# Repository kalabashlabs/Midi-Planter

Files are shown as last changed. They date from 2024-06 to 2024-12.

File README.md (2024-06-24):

# Midi-Planter 1.4
Midi Planter is a midi instrument that senses bio-signals in the roots and the soil of a house plant. The ranges of the bio-signals are mapped to midi notes ands sent to a computer, smartphone or analog synthesizer. 

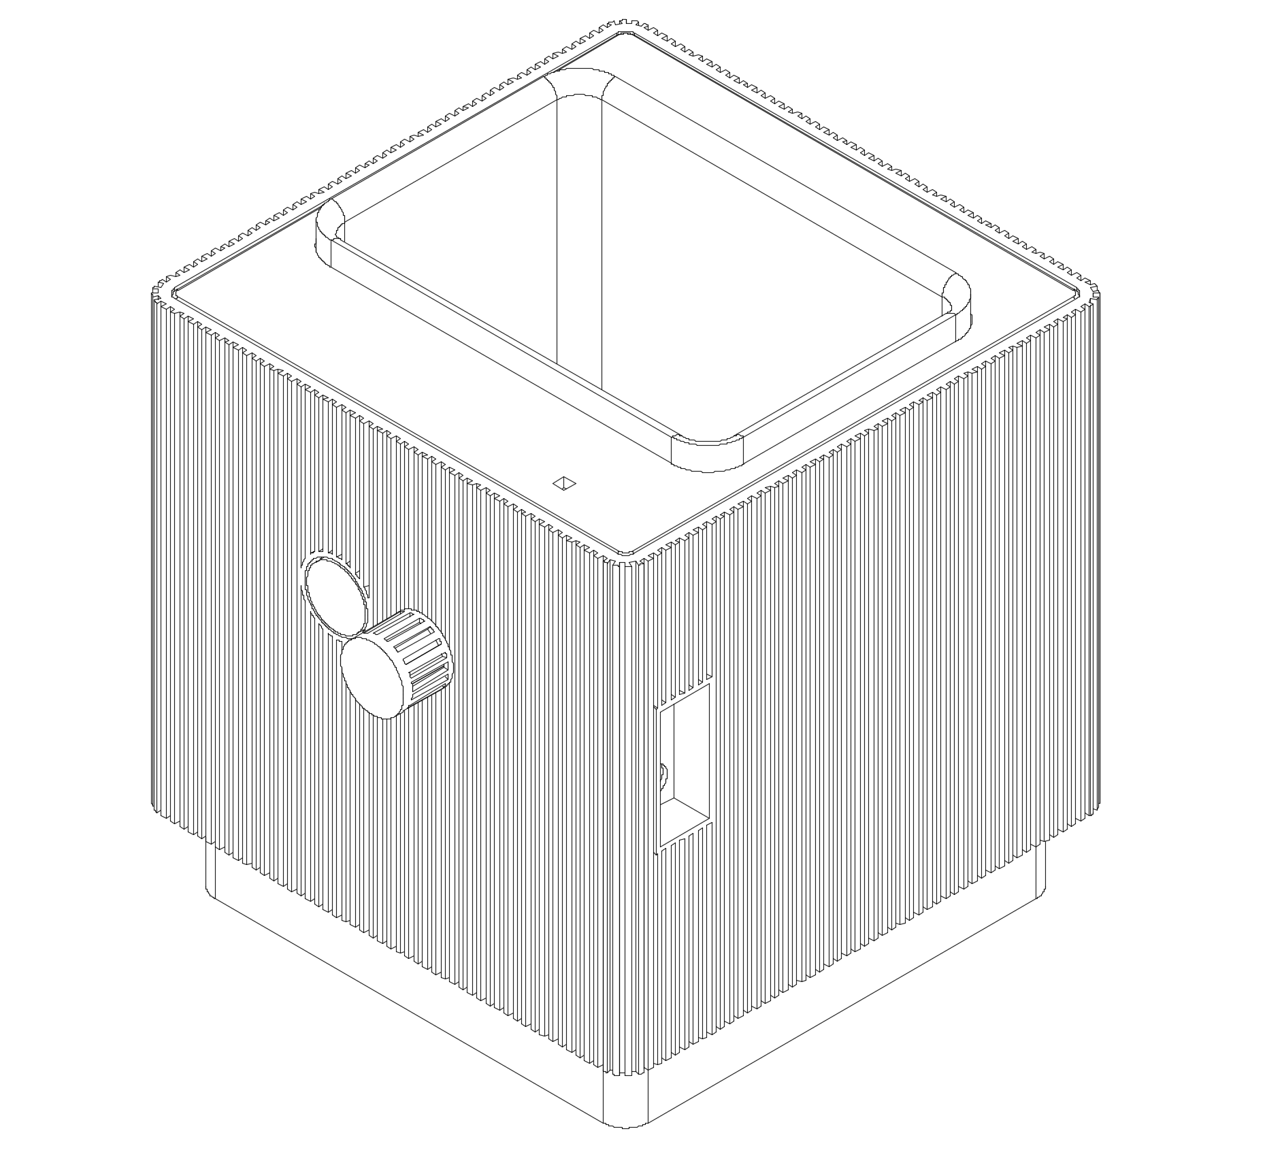
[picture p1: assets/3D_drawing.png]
Sketch of Midi-Planter


## Introduction
This repository contains the source code and documentation for a MIDI device that measures bio signals from plant roots and soil, converting them into MIDI messages using a custom PCB and an Adafruit Trinket M0.

## Features & Compatibility
- **Musical Scales:** Bio signals that are measured can be mapped to Chromatic, Major, Minor, Indian and Dorian.
- **MIDI OFF:** Pause midi messages sent to external device.
- **Open Source:** Designed specifically community collaboration.
- **Adafruit Trinket M0:** Utilizes the Adafruit Trinket M0 for processing and communication.
- **Connectability:** Connect to any instrument that accepts midi-In.  

## Getting Started

### Prerequisites
- PCB Setup Guide
- USB cable
- 3.5mm TRS Cable
- Arduino IDE

### Installation
1. Clone the repository:
   ```sh
   git clone https://github.com/kalabashlabs/Midi-Planter.git
   cd Midi-Planter

### Setup Firmware
Follow the [MP14 Firmware Setup Guide w/Arduino Trinket M0](https://github.com/kalabashlabs/Midi-Planter/tree/9c78c0cd12679d66a3d97c33ffdac4fd24a90cb2/firmware) Guide

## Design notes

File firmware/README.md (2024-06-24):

# MP14 Firmware Setup Guide w/Arduino Trinket M0

## Introduction
This guide will walk you through the steps to connect an Adafruit Trinket M0 to the Arduino IDE on both macOS and Windows. You'll learn how to configure the board and upload the firmware to it.

## Requirements
- Assembled PCB w/Adafruit Trinket M0 [LINK]
- Micro USB cable
- Computer (macOS or Windows)
- Arduino IDE (latest version)

## Step-by-Step Guide

### 1. Install Arduino IDE
1. **Download and Install:**
   - Go to the [Arduino IDE download page](https://www.arduino.cc/en/software) and download the latest version for your operating system.
   - Install the Arduino IDE following the on-screen instructions.

### 2. Install Adafruit Board Support Package
1. **Open Arduino IDE:**
   - Launch the Arduino IDE on your computer.
   
2. **Add Board Manager URL:**
   - Go to `Arduino` > `Preferences` on macOS or `File` > `Preferences` on Windows.
   - In the `Additional Board Manager URLs` field, add the following URL: 
     ```
     https://adafruit.github.io/arduino-board-index/package_adafruit_index.json
     ```
   - Click `OK`.

3. **Open Boards Manager:**
   - Go to `Tools` > `Board` > `Boards Manager`.

4. **Install Adafruit SAMD Boards:**
   - In the Boards Manager, search for `Adafruit SAMD`.
   - Click `Install` on `Adafruit SAMD Boards` by Adafruit.

### 3. Connect Adafruit Trinket M0
1. **Connect the Trinket M0:**
   - Use a USB cable to connect the Trinket M0 to your computer.

2. **Select the Board:**
   - Go to `Tools` > `Board`.
   - Select `Adafruit Trinket M0`.

3. **Select the Port:**
   - Go to `Tools` > `Port`.
   - Select the port that corresponds to your Trinket M0. It should look something like `COMx` on Windows or `/dev/cu.usbmodemxxxx` on macOS.

### 4. Uploading Source Code
1. **Open or Create a Sketch:**
   - Create a new one.
   - Copy and Paste the MP14.14 code to the Arduino sketch

2. **Compile the Sketch:**
   - Click the checkmark icon to verify (compile) your sketch.

3. **Upload the Sketch:**
   - Click the right arrow icon to upload the sketch to the Trinket M0.
   - If the upload is successful, the on-board LED should start blinking.

### 5. Troubleshooting
1. **Driver Issues (Windows):**
   - If your Trinket M0 is not recognized, you might need to install the USB driver. Follow the instructions on the Adafruit website to install the necessary drivers.

2. **Resetting the Trinket M0:**
   - If the upload fails, double-click the reset button on the Trinket M0 to enter bootloader mode (the red LED should pulse). Try uploading the sketch again.

### Conclusion
You have successfully set up your Adafruit Trinket M0 with the Arduino IDE and uploaded your first sketch. 

For more information and troubleshooting, refer to the [Adafruit Learning System](https://learn.adafruit.com/adafruit-trinket-m0-circuitpython-arduino) or the [Arduino Forums](https://forum.arduino.cc/).

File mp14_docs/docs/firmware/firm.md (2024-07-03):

# MP14 Firmware Setup Guide

[See on Github](https://github.com/kalabashlabs/Midi-Planter/tree/abc15cf49541974a32a134d85bc21599ec5fb134/firmware)

## 1. Install Arduino IDE

### Download and Install:

- Go to the [Arduino IDE download page](https://www.arduino.cc/en/software) and download the latest version for your operating system.
- Install the Arduino IDE following the on-screen instructions.

## 2. Install Adafruit Board Support Package

### Open Arduino IDE:

- Launch the Arduino IDE on your computer.

### Add Board Manager URL:

- Go to **Arduino > Preferences** on macOS or **File > Preferences** on Windows.
- In the **Additional Board Manager URLs** field, add the following URL: `https://adafruit.github.io/arduino-board-index/package_adafruit_index.json`
- Click **OK**.

### Open Boards Manager:

- Go to **Tools > Board > Boards Manager**.

### Install Adafruit SAMD Boards:

- In the Boards Manager, search for **Adafruit SAMD**.
- Click **Install** on **Adafruit SAMD Boards** by Adafruit.

## 3. Connect Adafruit Trinket M0

### Connect the Trinket M0:

- Use a USB cable to connect the Trinket M0 to your computer.

### Select the Board:

- Go to **Tools > Board**.
- Select **Adafruit Trinket M0**.

### Select the Port:

- Go to **Tools > Port**.
- Select the port that corresponds to your Trinket M0. It should look something like **COMx** on Windows or **/dev/cu.usbmodemxxxx** on macOS.

## 4. Uploading Source Code

### Open or Create a Sketch:

- Create a new one.
- Copy and paste the MP14.14 code to the Arduino sketch.

### Compile the Sketch:

- Click the checkmark icon to verify (compile) your sketch.

### Upload the Sketch:

- Click the right arrow icon to upload the sketch to the Trinket M0.
- If the upload is successful, the on-board LED should start blinking.

## 5. Troubleshooting

### Driver Issues (Windows):

- If your Trinket M0 is not recognized, you might need to install the USB driver. Follow the instructions on the Adafruit website to install the necessary drivers.

### Resetting the Trinket M0:

- If the upload fails, double-click the reset button on the Trinket M0 to enter bootloader mode (the red LED should pulse). Try uploading the sketch again.

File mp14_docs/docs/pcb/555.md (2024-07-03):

- Solder the 555 timer onto U6

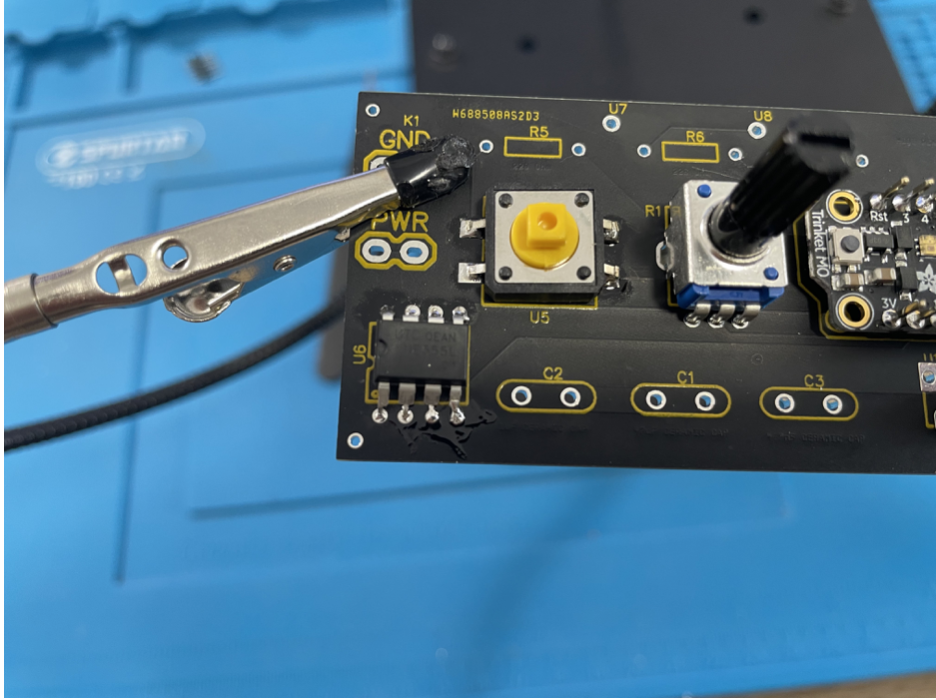
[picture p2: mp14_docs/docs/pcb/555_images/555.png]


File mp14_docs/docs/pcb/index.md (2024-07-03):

# Printed Circuit Board

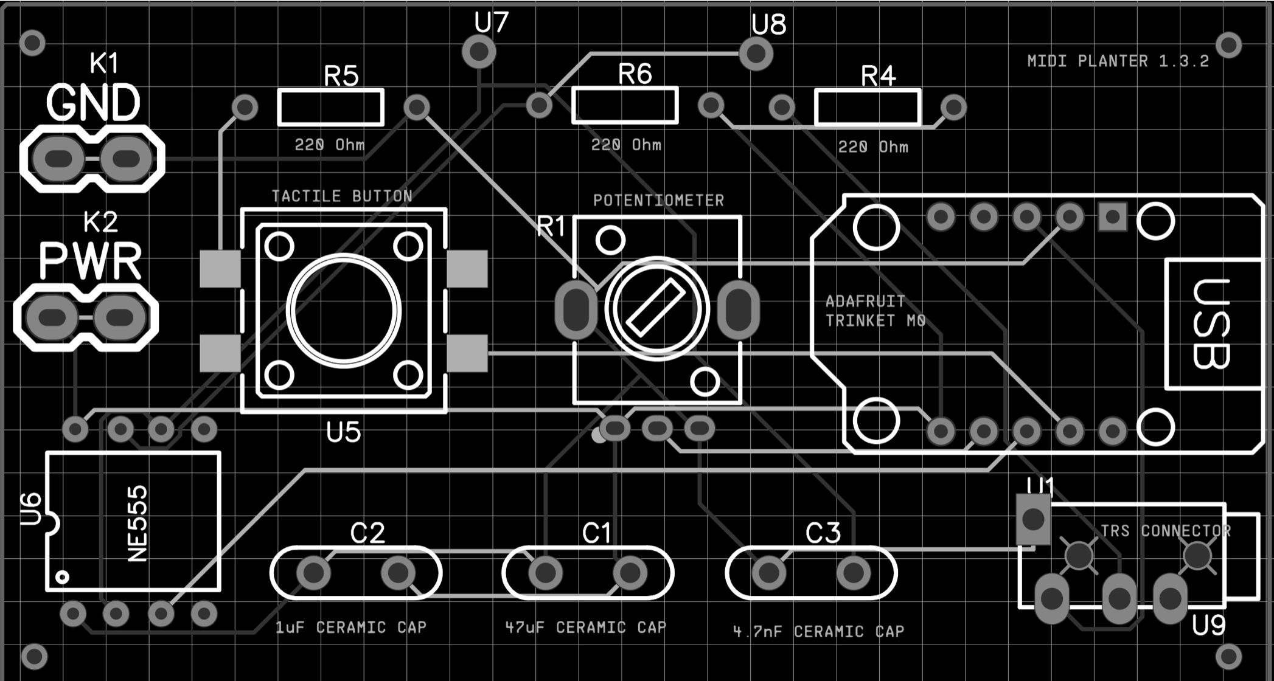
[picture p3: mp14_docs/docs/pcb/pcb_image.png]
pcb


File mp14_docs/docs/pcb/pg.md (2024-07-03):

The GND and PWR connectors are optional for a battery pack. The recommended voltage for the circuit is 3.5V. Two CR2032 cell batteries were tested and worked well.

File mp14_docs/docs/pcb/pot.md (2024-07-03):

- Place the potentiometer into the R1 placement on the PCB. It should fit snug. Solder the Potentiometer onto R1

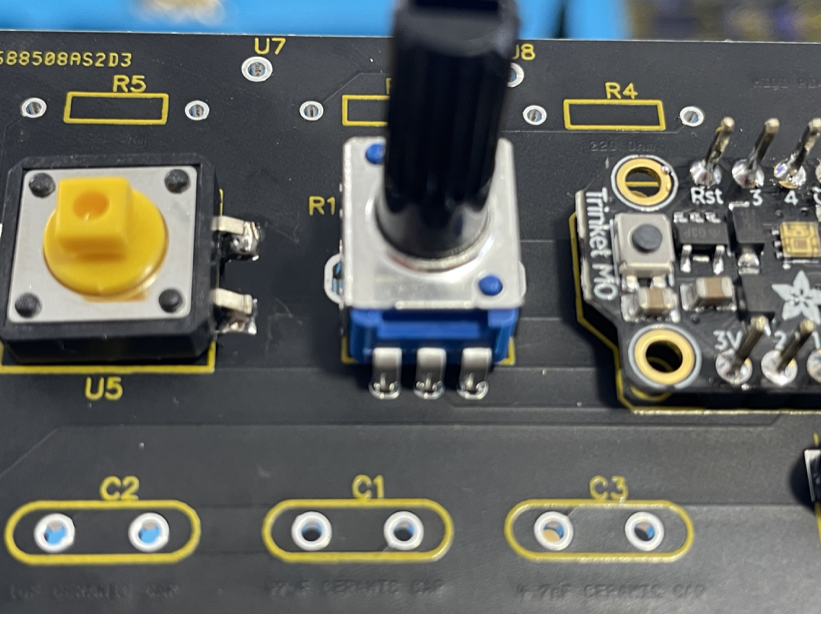
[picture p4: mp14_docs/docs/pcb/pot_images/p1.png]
pot1

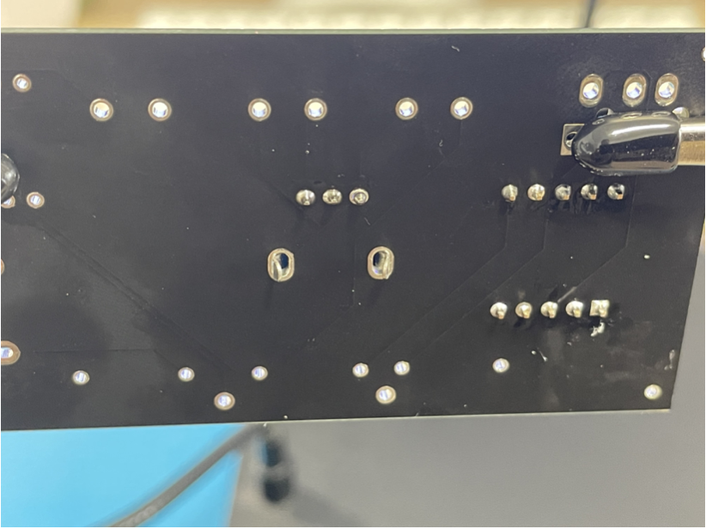
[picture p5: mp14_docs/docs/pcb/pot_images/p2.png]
pot2


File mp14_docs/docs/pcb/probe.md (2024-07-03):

- Cut two pieces of the 0.9mm copper coil at around 72 millimeters.

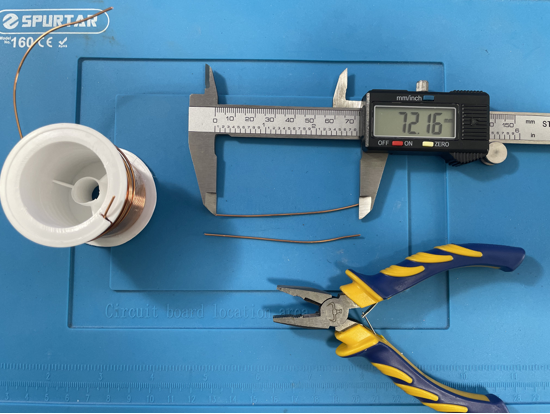
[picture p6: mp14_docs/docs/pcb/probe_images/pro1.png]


- Sand off the insulating layer of the coils with sanding paper. Wear gloves to protect hands from sand paper.

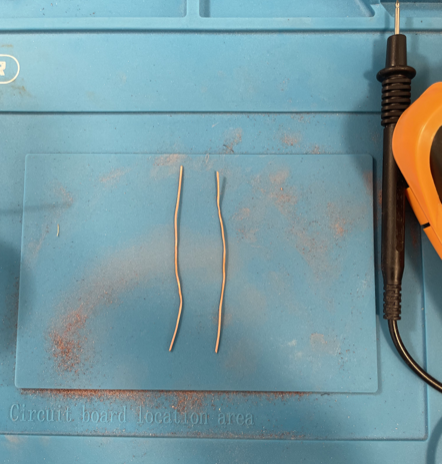
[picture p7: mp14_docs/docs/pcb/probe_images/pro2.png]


- Set your digital multimeter to continuity mode. To test, touch the multimeter probes to the ends of the copper wire one at a time. If the multimeter beeps or buzzes, it indicates successful end-to-end continuity. If there is no sound, it means the insulating layer on the wire needs to be sanded more thoroughly. Test multiple areas of the probe to make sure the insulating layer is evenly sanded off.

- Solder the two copper coil strips to U7 and U8 on the pcb.

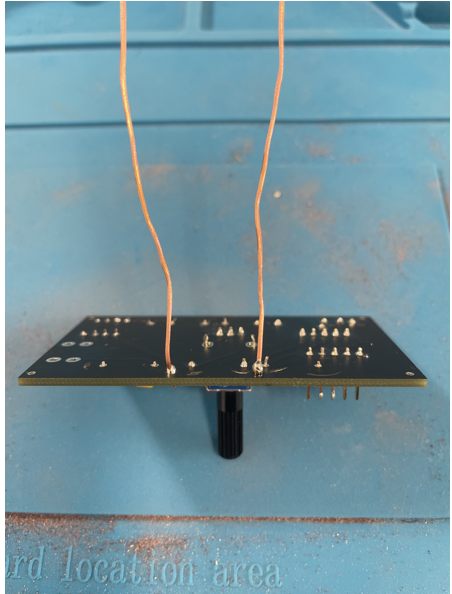
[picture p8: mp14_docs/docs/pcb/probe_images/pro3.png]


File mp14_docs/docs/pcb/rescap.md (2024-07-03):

Solder the resistors and capacitors

- Resistor R5 = 220 ohm
- Resistor R6 = 220 ohm
- Resistor R4 = 220 ohm
- Capacitor C2 = 1uF
- Capacitor C1 =47uf
- Capacitor C3 = 4.7nF

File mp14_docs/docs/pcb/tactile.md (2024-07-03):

- Bend all the pins on the tactile switch so that they are faced outward instead of down. Using a wire cutter or a scissor, cut the pins so they fit onto the U5 area on the PCB. Below is a picture of what it should look like before(left) and after(right).

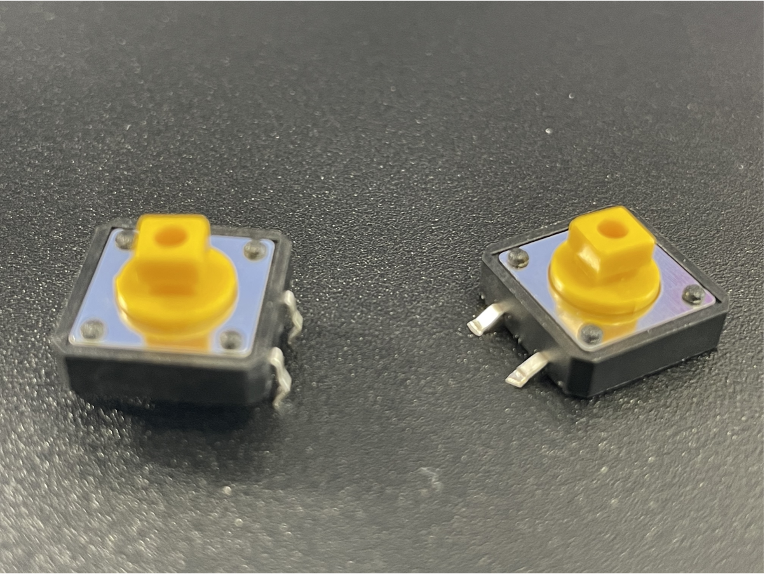
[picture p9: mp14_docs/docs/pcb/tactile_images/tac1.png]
tac1


- With the soldering iron, solder the four onto the four pin areas of U5 then, solder the tactile switch onto U5

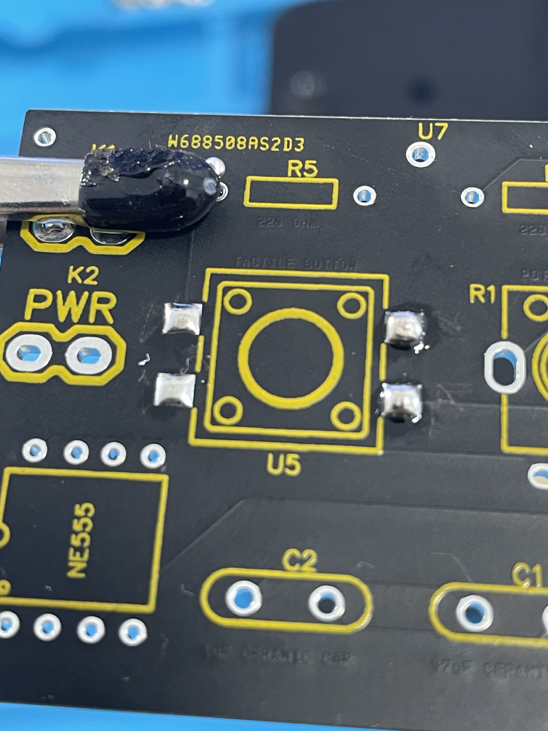
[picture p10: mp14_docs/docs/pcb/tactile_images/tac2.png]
tac2

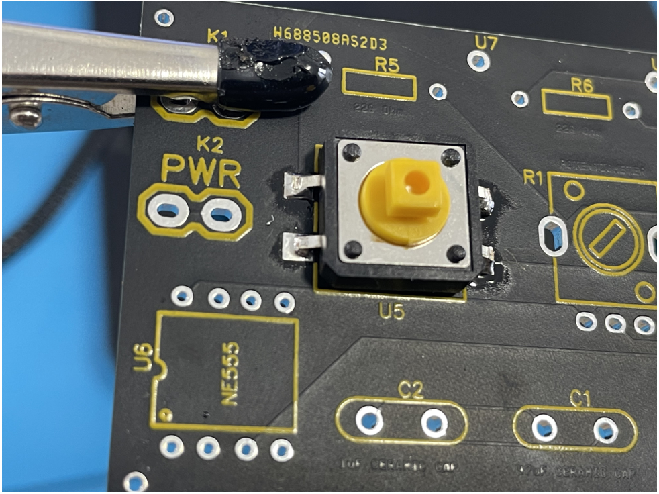
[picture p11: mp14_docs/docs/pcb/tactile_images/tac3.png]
tac3


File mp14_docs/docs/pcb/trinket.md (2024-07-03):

- Snap off 2 sets of 5 header pins that come with the trinket M0. Solder the headers on to the board where the trinket M0 is outlined. The longer sides of the pins should face up.

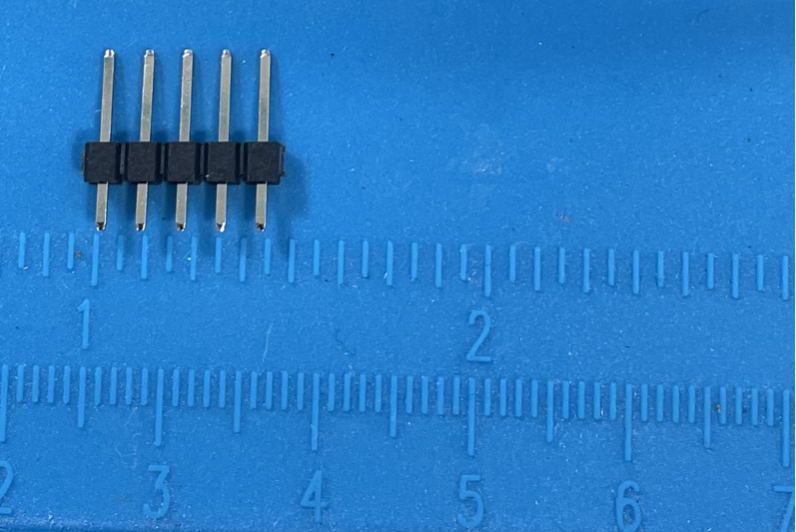
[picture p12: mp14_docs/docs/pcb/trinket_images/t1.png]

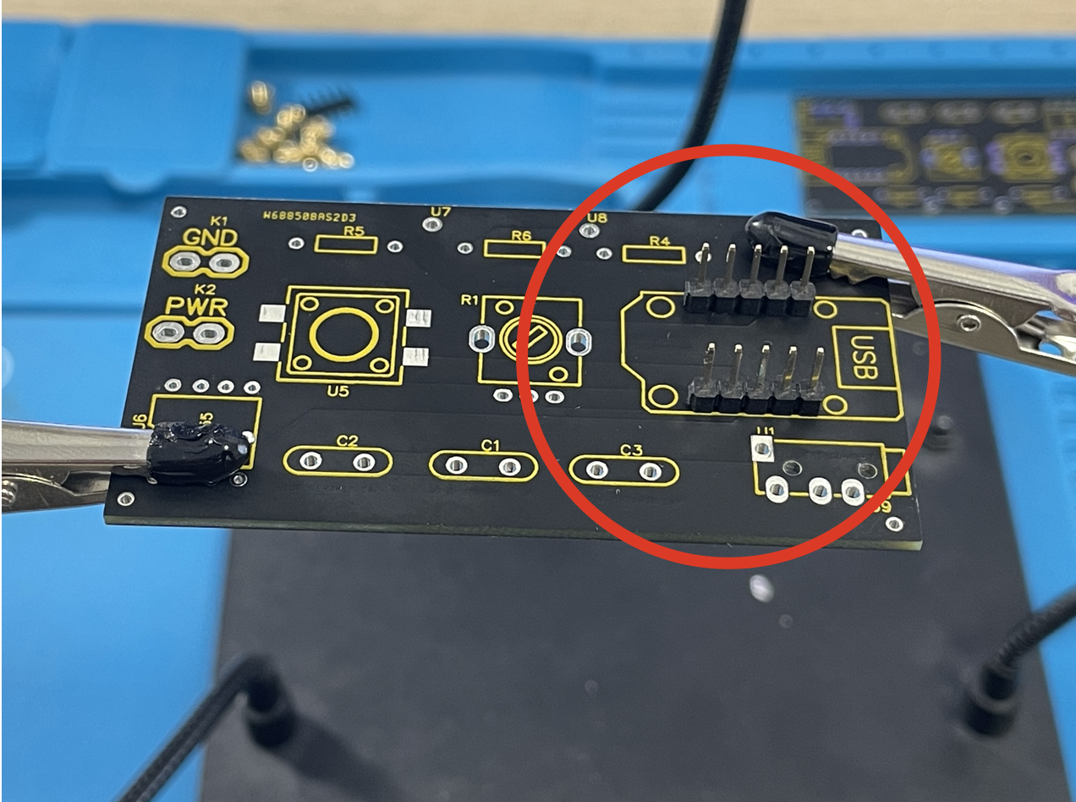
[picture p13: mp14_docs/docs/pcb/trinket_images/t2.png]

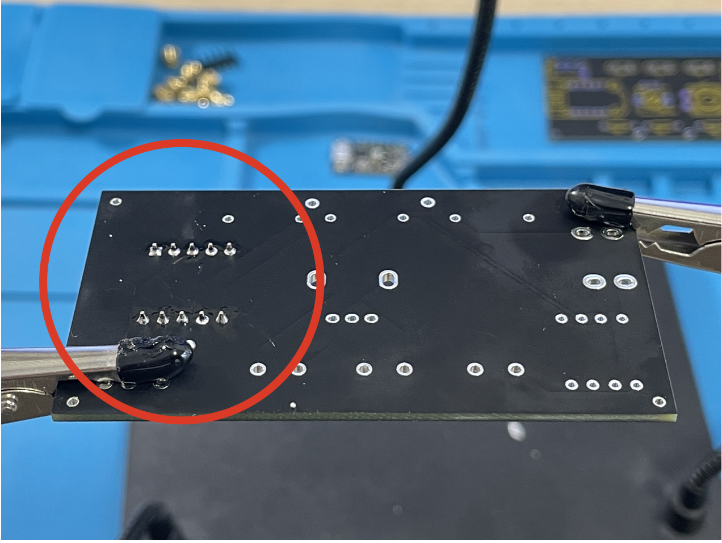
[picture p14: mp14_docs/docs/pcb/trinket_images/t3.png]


- Solder the trinket M0 onto the headers.

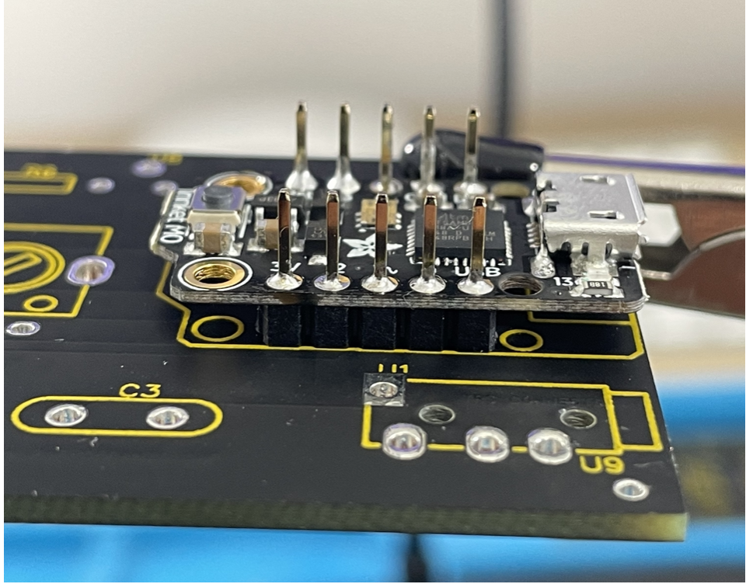
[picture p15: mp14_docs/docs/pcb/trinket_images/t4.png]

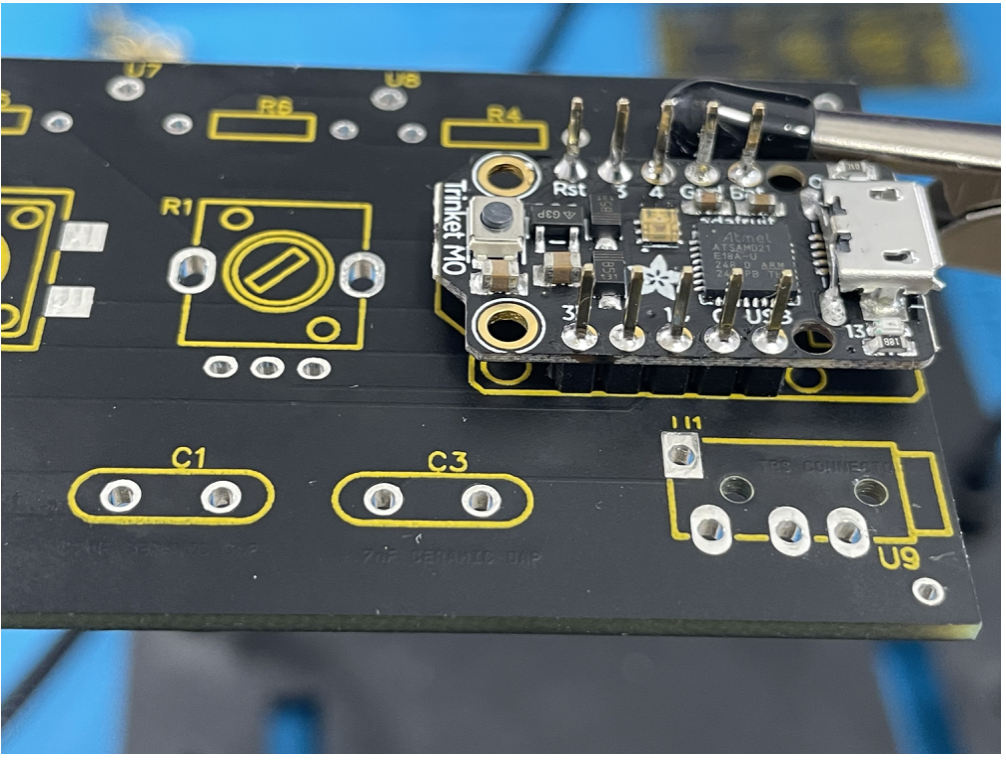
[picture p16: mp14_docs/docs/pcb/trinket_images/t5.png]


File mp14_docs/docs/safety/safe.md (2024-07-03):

# Safety

**Work in a Well-Ventilated Area:**

- Always solder in a well-ventilated space to avoid inhaling fumes. Use a fume extractor if possible.

**Wear Protective Gear:**

- **Safety Glasses:** Protect your eyes from solder splashes.
- **Heat-Resistant Gloves:** Prevent burns from the soldering iron and hot solder.

**Use a Proper Soldering Iron Stand:**

- Always place the soldering iron in a stand when not in use to prevent accidental burns and fire hazards.

**Avoid Flammable Materials:**

- Keep your work area clear of flammable materials. Ensure the soldering iron does not come into contact with paper, plastic, or other flammable objects.

**Handle Soldering Iron Carefully:**

- Never touch the tip of the soldering iron. Be mindful of where you place your hands to avoid accidental burns.

**Clean Soldering Tip Regularly:**

- Use a damp sponge or brass wire cleaner to keep the soldering tip clean, ensuring efficient and safe soldering.

**Avoid Inhaling Solder Fumes:**

- Use lead-free solder to minimize health risks. Ensure good ventilation or use a fume extractor.

**Properly Dispose of Waste:**

- Dispose of used solder and electronic components according to local regulations. Do not throw them in regular trash.

**Sanding Copper Wire Safety**

**Wear Protective Gear:**

- **Safety Glasses:** Protect your eyes from copper dust and particles.
- **Dust Mask:** Prevent inhalation of copper dust.
- **Gloves:** Protect your hands from the sanding skin with sandpaper.

**Secure the Wire: (Optional)**

- Use a vise or clamp to securely hold the copper wire in place while sanding to prevent slipping and accidental injury. [Vise Clamp](https://www.printables.com/model/65687/files)

**Use Appropriate Sanding Tools:**

- Use fine-grit sandpaper to remove the insulator layer. Avoid using power tools, as they can remove too much material and generate excessive dust.

**Work in a Well-Ventilated Area:**

- Sand in a well-ventilated space to ensure you are not breathing in copper dust. An outdoor workspace is ideal.

**Clean Up Properly:**

- After sanding, clean the work area thoroughly to remove copper dust. Wash your hands and any exposed skin to avoid prolonged contact with copper particles.

**Avoid Excessive Force:**

- Apply gentle, even pressure while sanding to avoid damaging the wire and to maintain control of the sanding process.

**Store Tools Safely:**

- After use, store sandpaper and other tools in a safe place to prevent accidental contact.

## General Safety Tips

**Read Instructions Carefully:**

- Follow all steps as outlined in the manual. Do not skip steps or take shortcuts.

**Keep a First Aid Kit Handy:**

- In case of minor injuries, have a first aid kit available for immediate treatment.

**Seek Help If Needed:**

- Don't hesitate to ask for assistance if you're unsure about any part of the process.

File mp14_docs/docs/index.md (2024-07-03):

# MP14 Overview

Kalabash Labs' MP14 is a planter and a polyphonic MIDI controller which utilizes bioelectrical signals from living organisms inside of soil as a source of input, converting them into control voltages that can be interpreted as notes within any desired chromatic scale.

**Features and Compatibility**

- Musical Scales: Bio signals that are measured can be mapped to Chromatic, Major, Minor, Indian and Dorian.
- MIDI OFF: Pause midi messages sent to external device.
- Open Source: Designed specifically community collaboration.
- Adafruit Trinket M0: Utilizes the Adafruit Trinket M0 for processing and communication.
- Connectability: Connect to any instrument that accepts midi-In.

**References**

- [galvanic_midi](https://github.com/jarvisb1/galvanic_midi/tree/master)
- [Biodata Sonification Breadboard Kit](https://github.com/electricityforprogress/BiodataSonificationBreadboardKit)

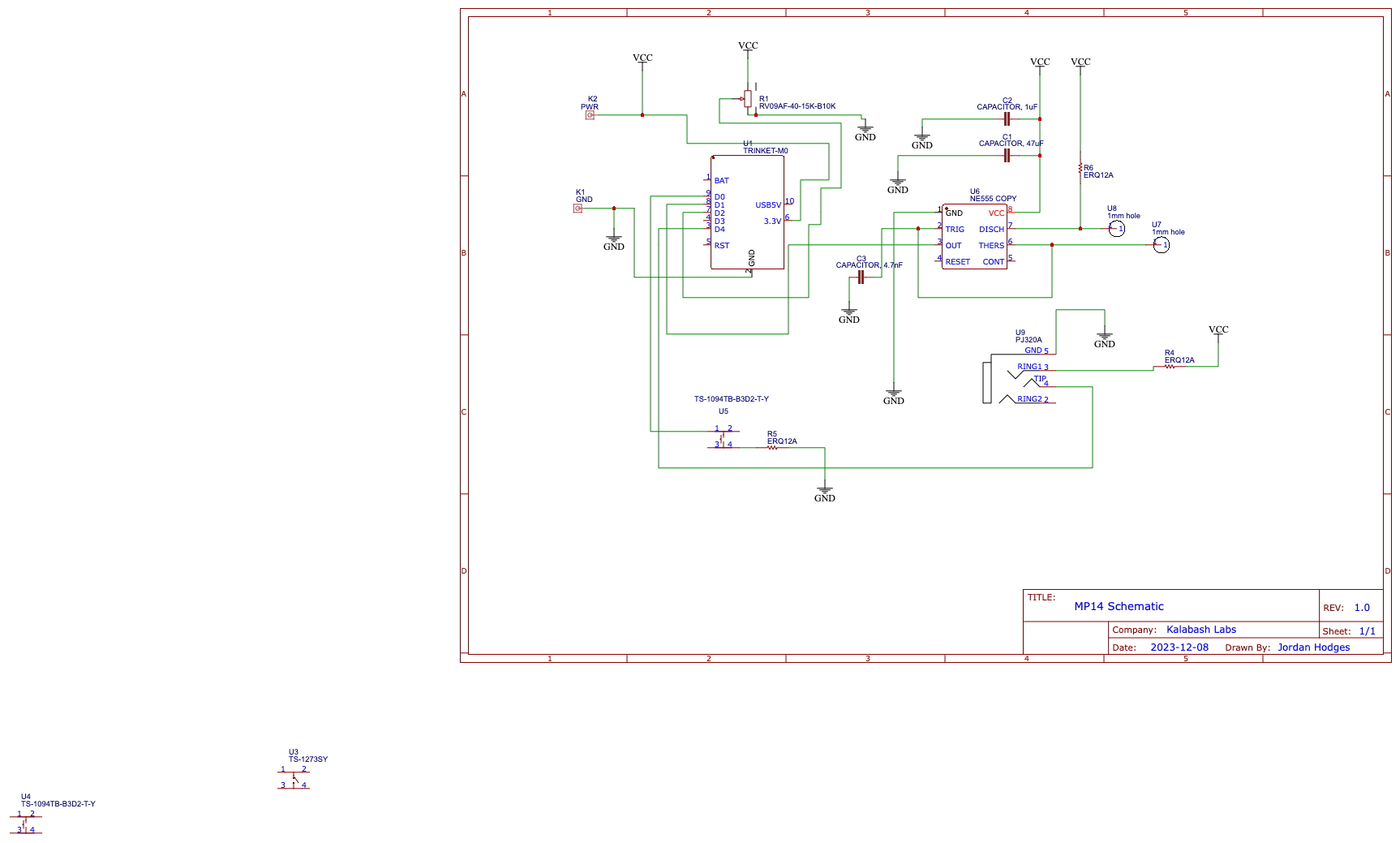
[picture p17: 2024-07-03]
assets/schematics/Schematic_MIDI-PLANTER1_4.png

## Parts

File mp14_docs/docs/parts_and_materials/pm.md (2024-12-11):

# Parts and Materials

**PCB Parts**

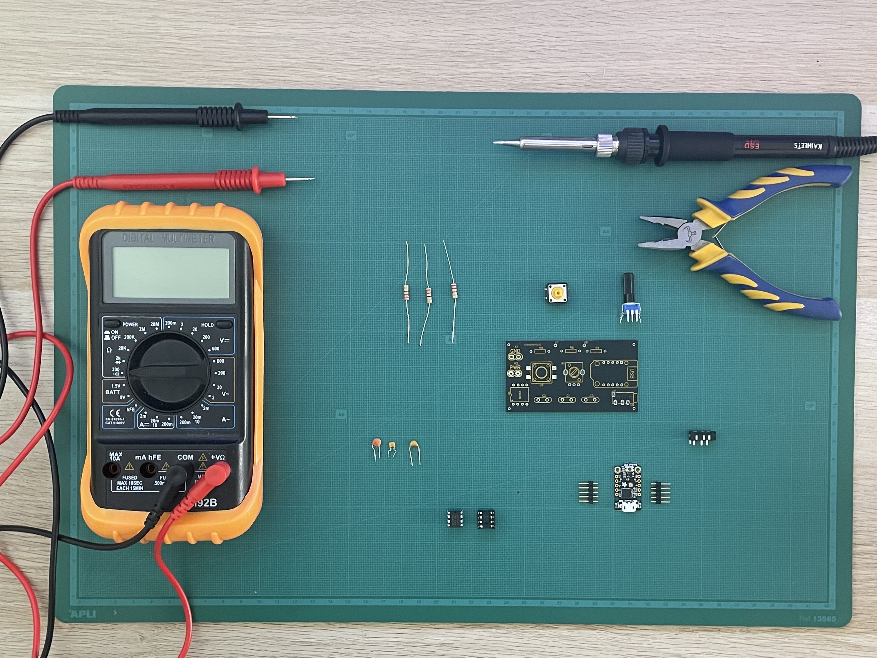
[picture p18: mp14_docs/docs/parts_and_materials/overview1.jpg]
PCB_Image


Below is a list of components needed to assmeble the pcb. It is recommended to source these components locally from a Maker Space/ Fabrication Lab or a local electronics store. You can find the Gerber file for the PCB [here](https://github.com/kalabashlabs/Midi-Planter/tree/38d511a70ebe548d43128dbe252c7a7642a91098/assets/schematics).

| Part | Online | Quantity |
| --- | --- | --- |
| Adafruit Trinket M0 | [Adafruit](https://www.adafruit.com/product/3500) | 1 |
| 555 Timer | [AMZN_ES](https://shorturl.at/HQzQk) / [AMZN_US](https://shorturl.at/2IgPi) | 1 |
| 220 Ohm Resistor | [Adafruit](https://www.adafruit.com/product/2780) | 3 |
| 1 uF 35V Ceramic Capacitor | [AMZN_ES]() / [AMZN_US](https://shorturl.at/93tgW) | 1 |
| 47 uF Ceramic Capacitor | [AMZN_ES](https://shorturl.at/sUhQ8) / [AMZN_US]() | 1 |
| 470 pF Ceramic Capacitor | [AMZN_ES](https://shorturl.at/R7DZH) / [AMZN_US]() | 1 |
| TRS Connector PJ320A | [AMZN_ES](https://shorturl.at/5Rtxn) / [AMZN_US]() | 1 |
| Tactile Switch | [Adafruit](https://www.adafruit.com/product/1009) | 1 |
| Potentiometer | [Diotronic](https://diotronic.com/de-ajuste-con-eje/11321-poten-vertical-10k-pcb-eje-6mm) | 1 |
| 0.9mm Copper Coil | [AMZN_ES](https://shorturl.at/LzUeT) / [AMZN_US]() | 1 |

**3D Printed Parts & Materials**

3D

- Planter
- PCB Bracket
- Hood
- Shell
- Pool
- Button
- Knob

These 3D Design Files can be found [here](https://github.com/kalabashlabs/Midi-Planter/tree/38d511a70ebe548d43128dbe252c7a7642a91098/assets/stl)

Below is a list of screws and nuts needed to assemble the 3D parts.

| Part | Online | Quantity |
| --- | --- | --- |
| M4 Screws | [Adafruit](https://www.adafruit.com/product/3500) | 6 |
| M4 Brass Nut Inserts | [AMZN_ES](https://shorturl.at/HQzQk) / [AMZN_US](https://shorturl.at/2IgPi) | 6 |

**Tools Needed for Assembly**

- Soldering Iron
- Solder
- 3D Printer
- Multimeter

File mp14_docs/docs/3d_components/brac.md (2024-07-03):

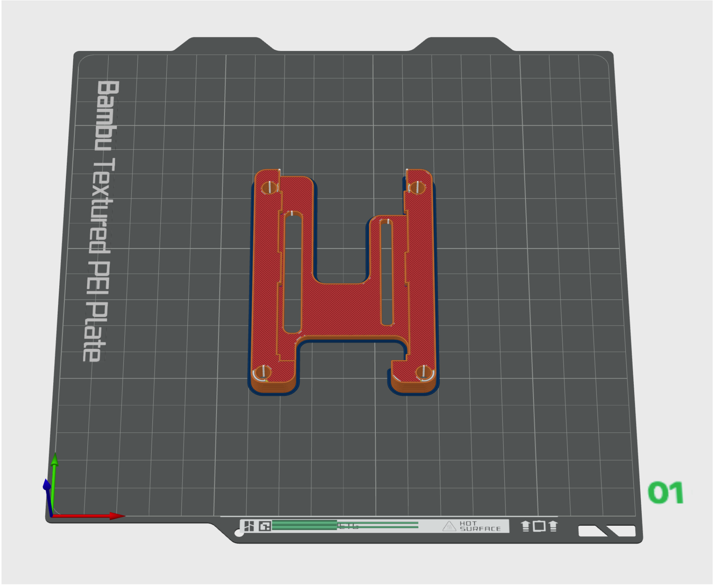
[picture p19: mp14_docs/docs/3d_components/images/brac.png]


PRINT SETTINGS:

- Material: PLA
- Layer Height: 0.3 mm
- Sparse Infill Density: 30%
- Support: No

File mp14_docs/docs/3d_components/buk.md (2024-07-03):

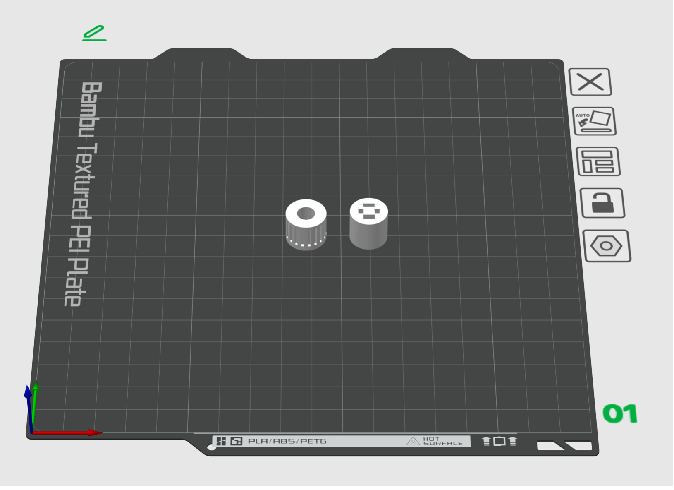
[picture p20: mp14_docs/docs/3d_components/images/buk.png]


PRINT SETTINGS:

- Material: PLA
- Layer Height: 0.3 mm
- Sparse Infill Density: 30%
- Support: No

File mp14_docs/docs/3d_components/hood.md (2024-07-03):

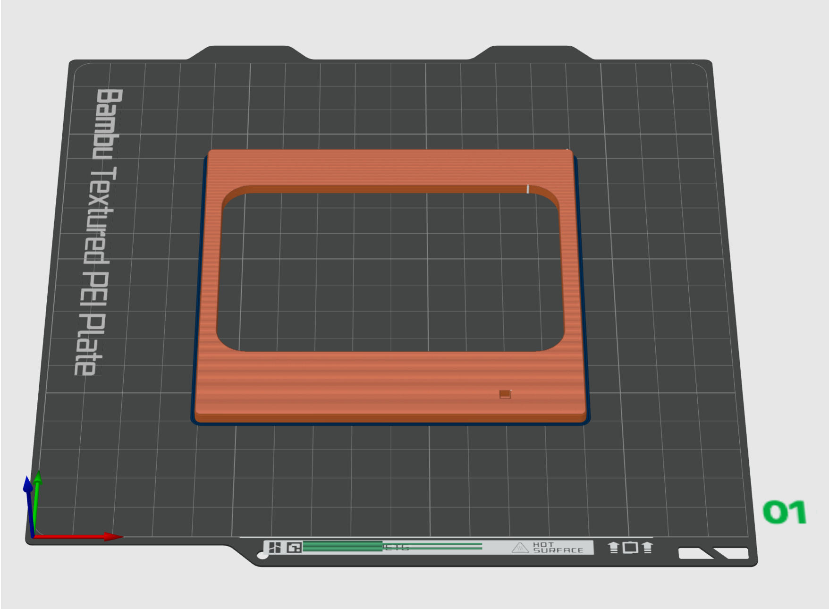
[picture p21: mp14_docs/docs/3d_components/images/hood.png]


PRINT SETTINGS:

- Material: PLA
- Layer Height: 0.3 mm
- Sparse Infill Density: 30%
- Support: No

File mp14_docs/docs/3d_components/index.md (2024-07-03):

# 3D Printed Components

These example printed components were printed using a Bambu Labs A1 mini. The recommended print settings are listed for Bambu Studio.

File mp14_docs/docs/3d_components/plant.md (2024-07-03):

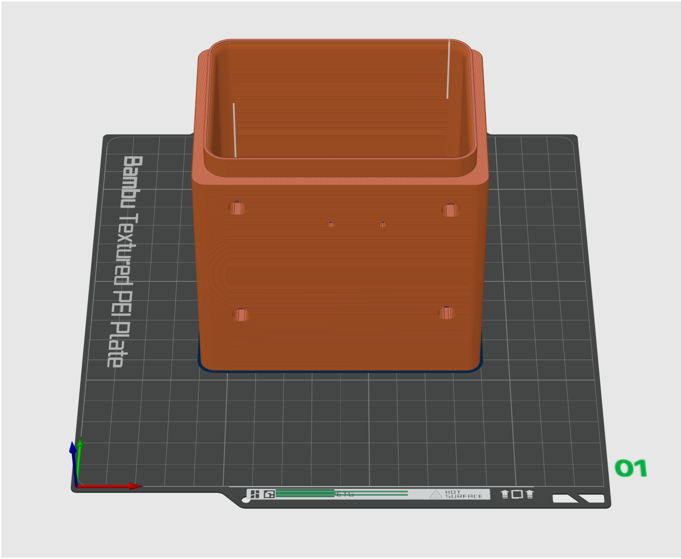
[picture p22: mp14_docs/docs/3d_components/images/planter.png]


PRINT SETTINGS:

- Material: PLA
- Layer Height: 0.3 mm
- Sparse Infill Density: 30%
- Support: No

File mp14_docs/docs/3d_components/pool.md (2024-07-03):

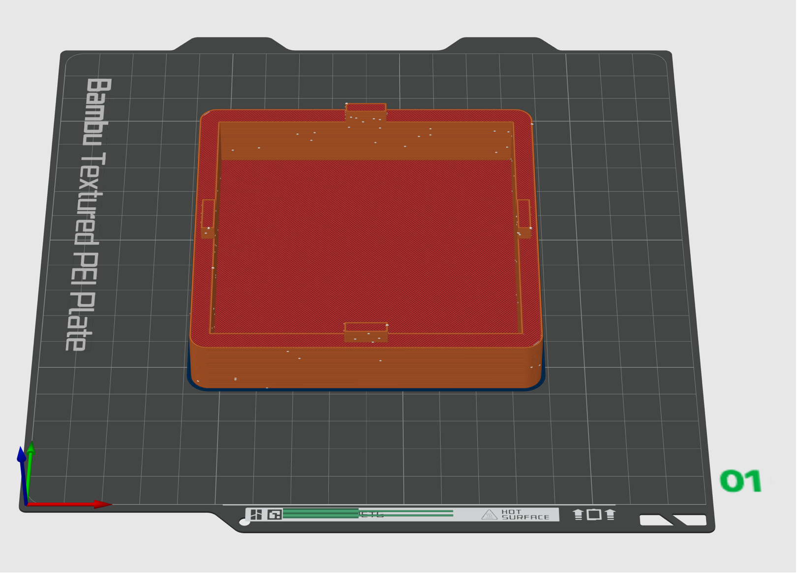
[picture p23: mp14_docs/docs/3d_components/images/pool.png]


PRINT SETTINGS:

- Material: PLA
- Layer Height: 0.3 mm
- Sparse Infill Density: 30%
- Support: No

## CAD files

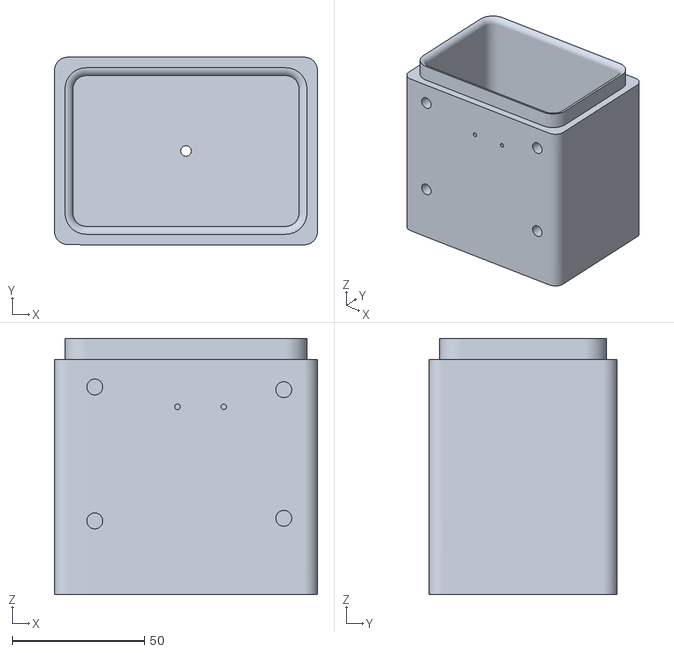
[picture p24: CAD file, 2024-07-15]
assets/stl/PLANTER.stl
99.5 x 71.0 x 97.0

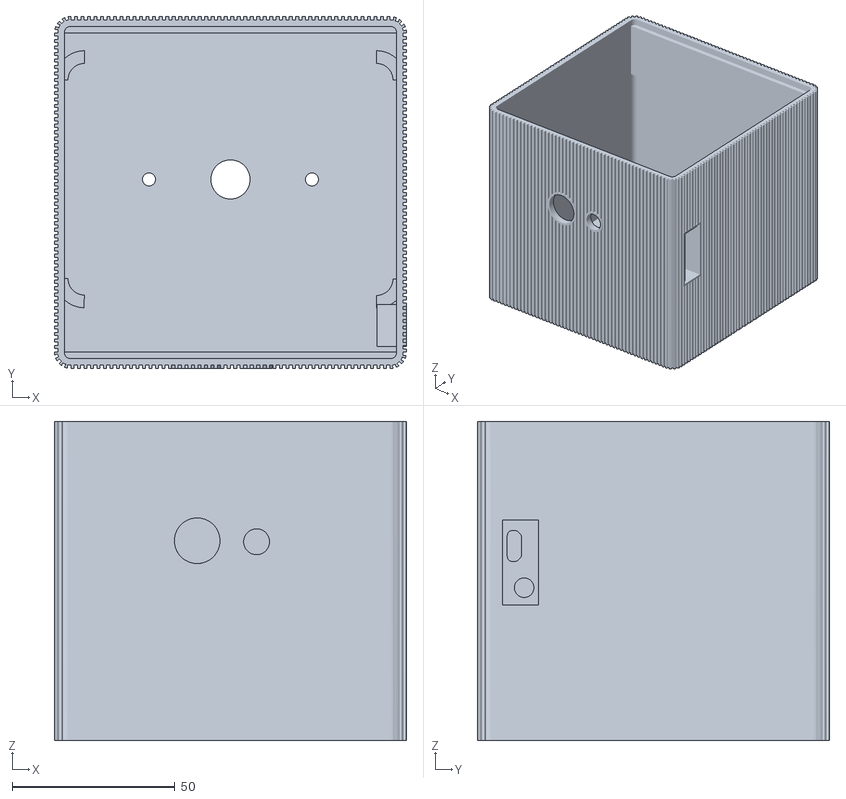
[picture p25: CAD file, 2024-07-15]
assets/stl/SHELL.stl
108.0 x 108.0 x 98.0

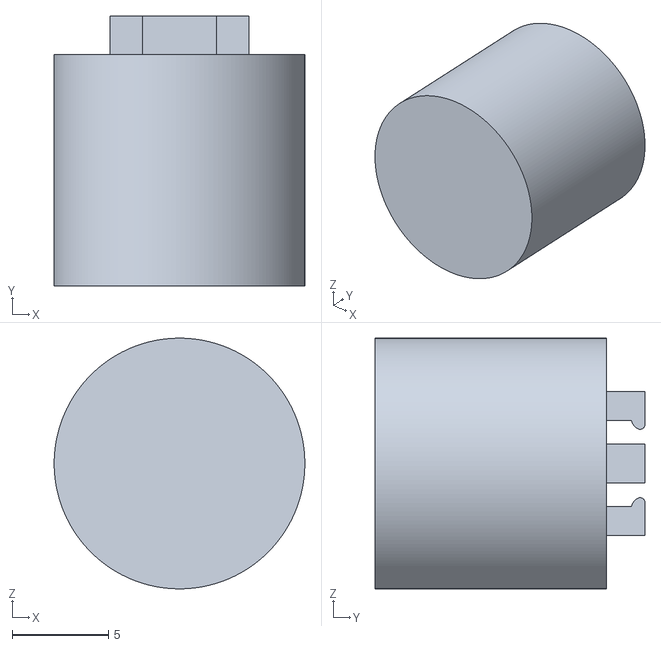
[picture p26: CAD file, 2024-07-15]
assets/stl/BUTTON.stl
13.0 x 14.0 x 13.0

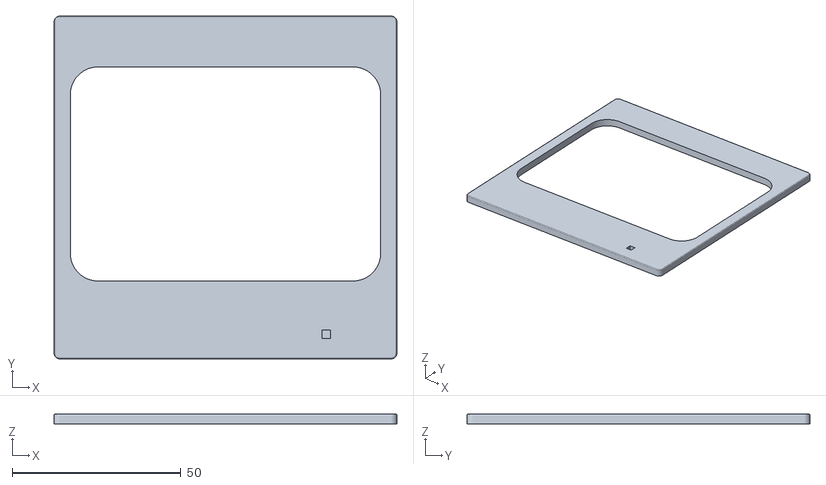
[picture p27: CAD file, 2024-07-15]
assets/stl/HOOD.stl
101.6 x 101.6 x 3.00

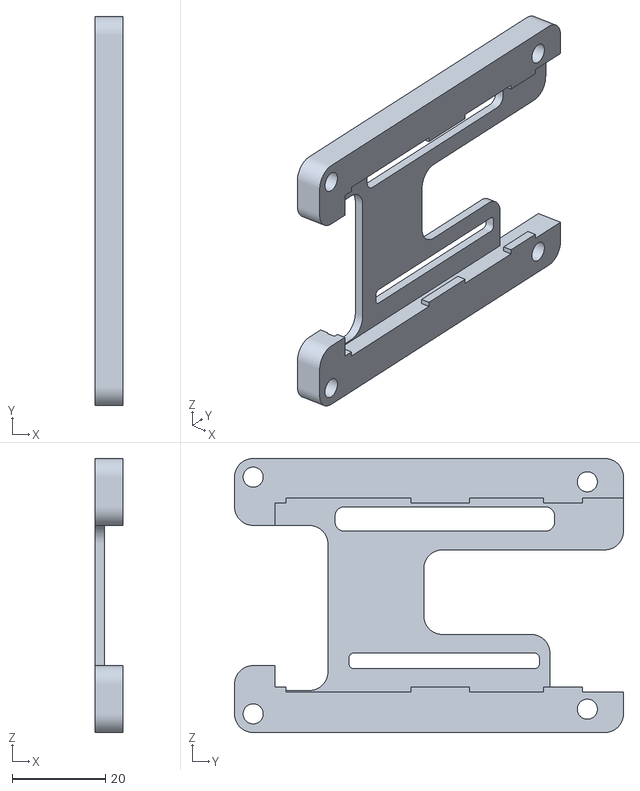
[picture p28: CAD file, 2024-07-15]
assets/stl/BRACKET.stl
6.00 x 83.3 x 58.7

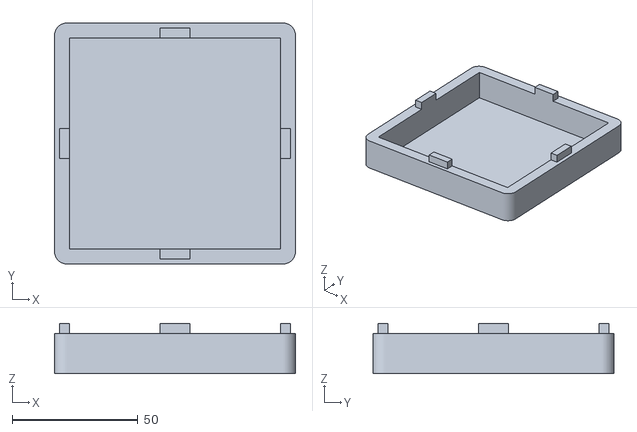
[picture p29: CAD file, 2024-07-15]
assets/stl/POOL.stl
96.0 x 96.0 x 20.0

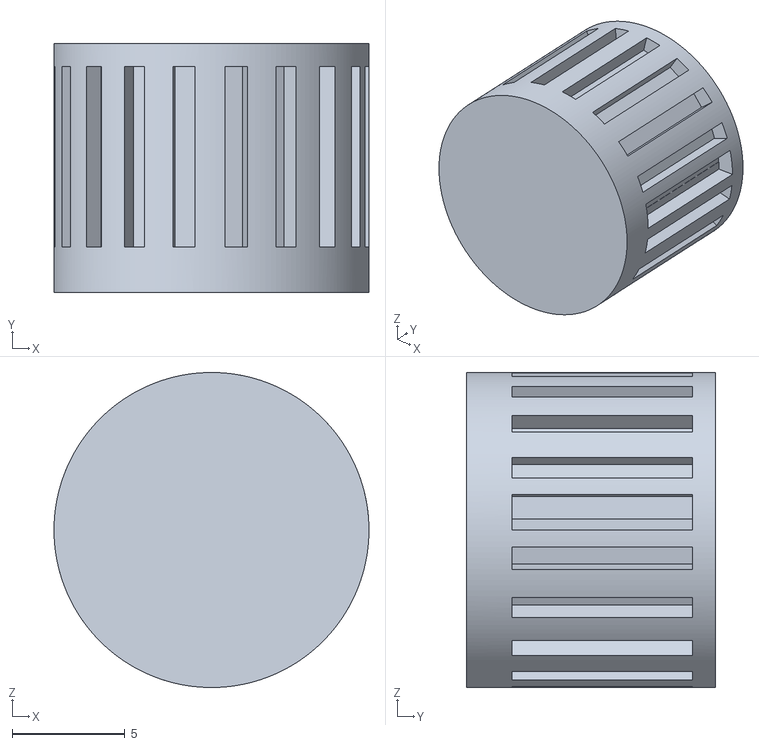
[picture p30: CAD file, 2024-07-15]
assets/stl/KNOB.stl
13.9 x 11.0 x 13.9

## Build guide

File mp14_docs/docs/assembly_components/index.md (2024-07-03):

Place the PCB board inside the bracket. The probes should go through the larger oval.

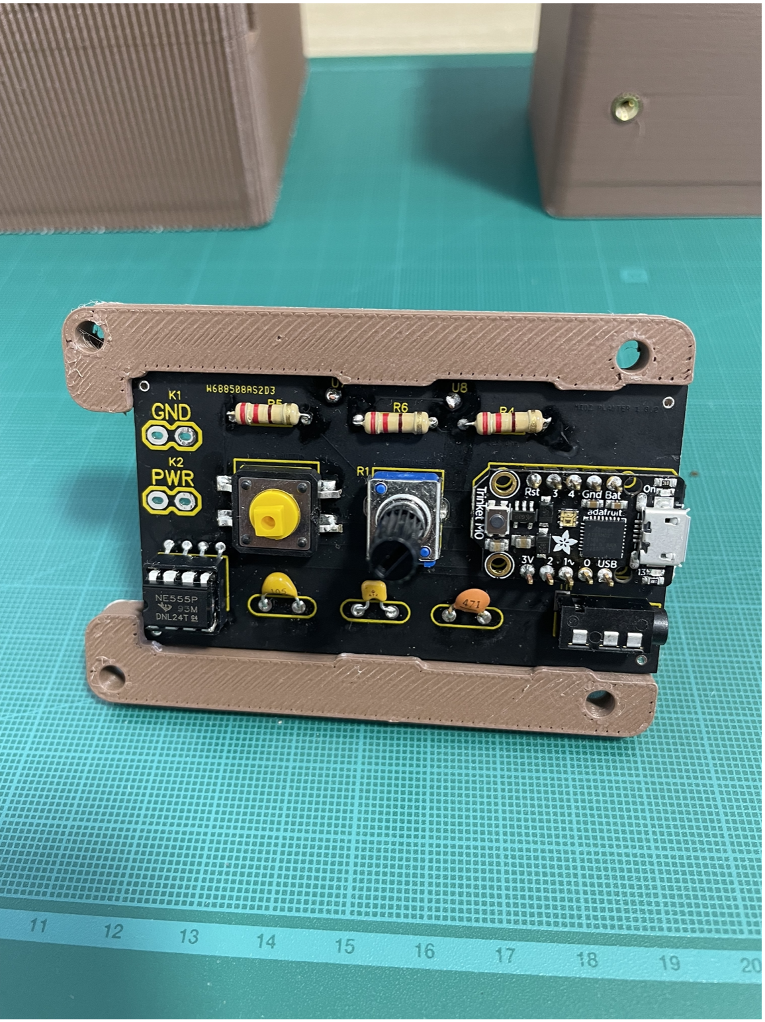
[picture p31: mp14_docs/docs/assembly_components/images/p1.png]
p1

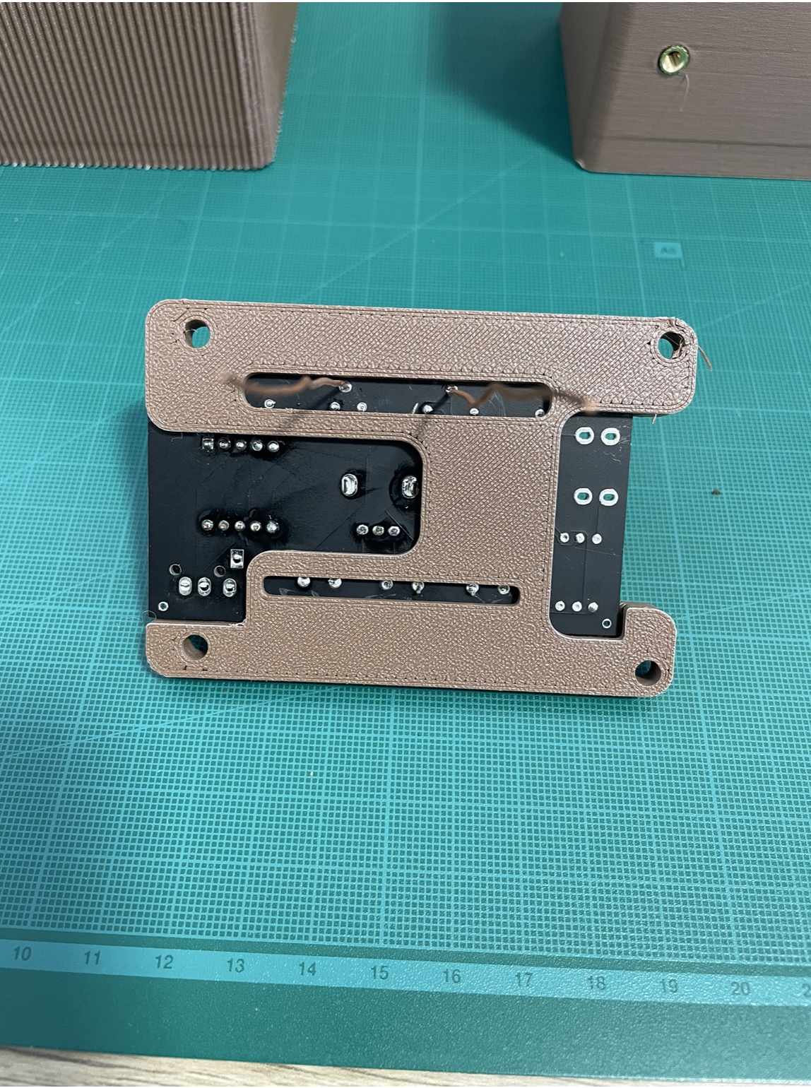
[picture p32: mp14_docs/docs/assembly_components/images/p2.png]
p2


Place four of the M4 brass inserts in the four holes on the front side of the planter. The smaller diameter side of the brass inserts should go inside the hole first.

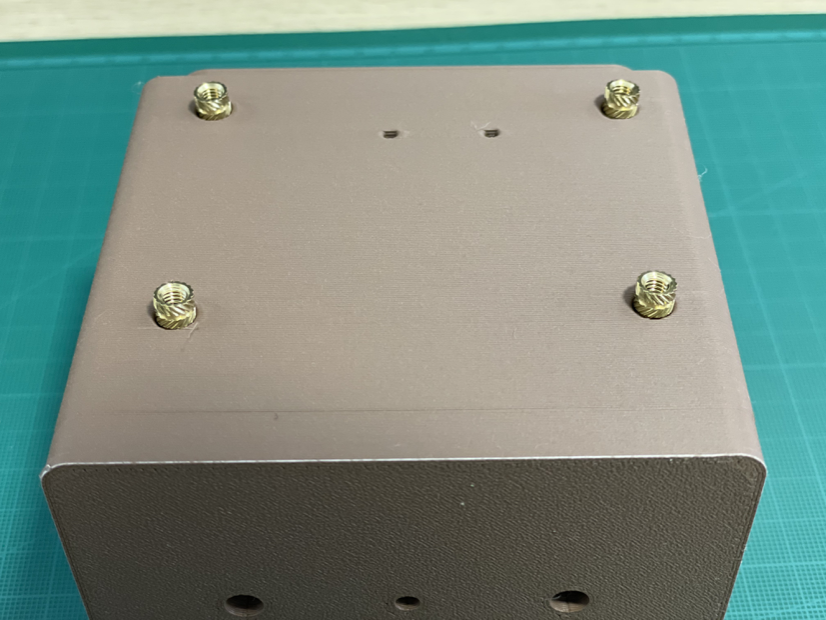
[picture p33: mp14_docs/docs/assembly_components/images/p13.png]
p13


With a soldering iron, hold the tip of the iron onto one brass insert and gently wait for the insert to slide into place. The heat of the iron contacting the insert will expand the PLA material so the insert will fit snug into the hole. Do this for all four holes.

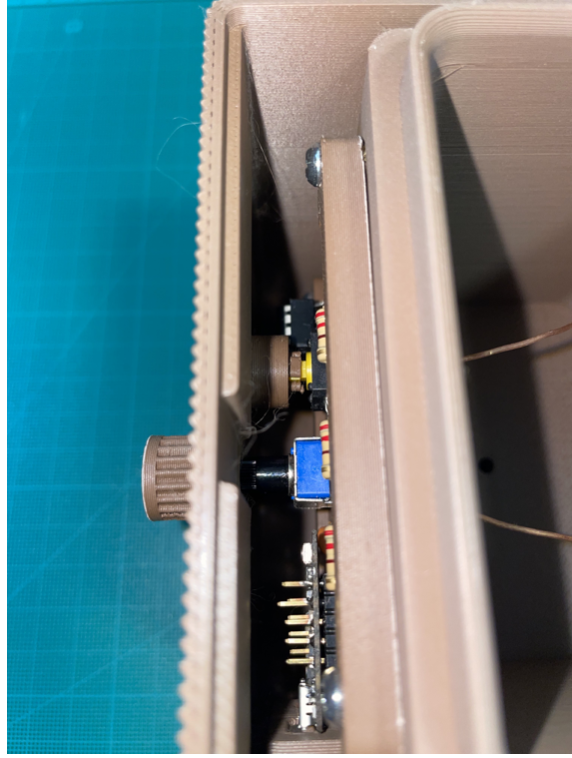
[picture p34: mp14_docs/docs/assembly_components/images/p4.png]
p4

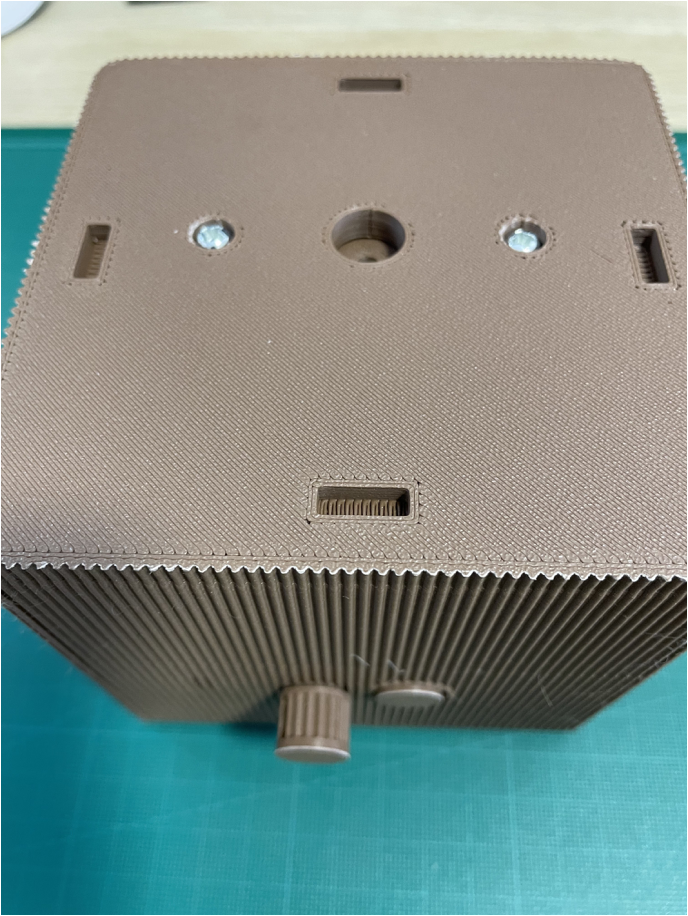
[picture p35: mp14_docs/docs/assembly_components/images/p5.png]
p5


Use the same technique from step 2 to place the inserts into the two holes at the bottom of the planter.

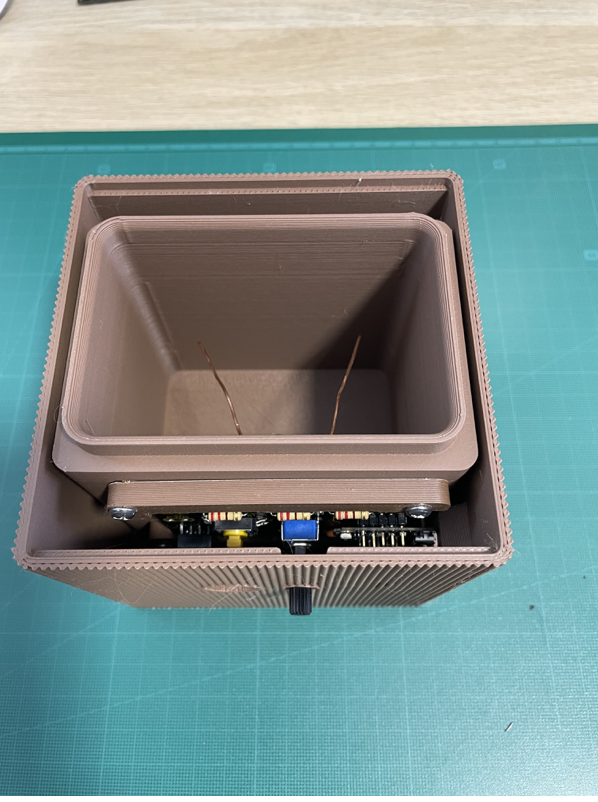
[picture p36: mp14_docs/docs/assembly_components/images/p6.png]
p6


Line the bracket up with the front of the planter and place four M4 screws through the four holes of the PCB Bracket. The copper wires goes through the two small holes on the front of the planter. Then, screw the four M4 screws to the planter with a screw driver.

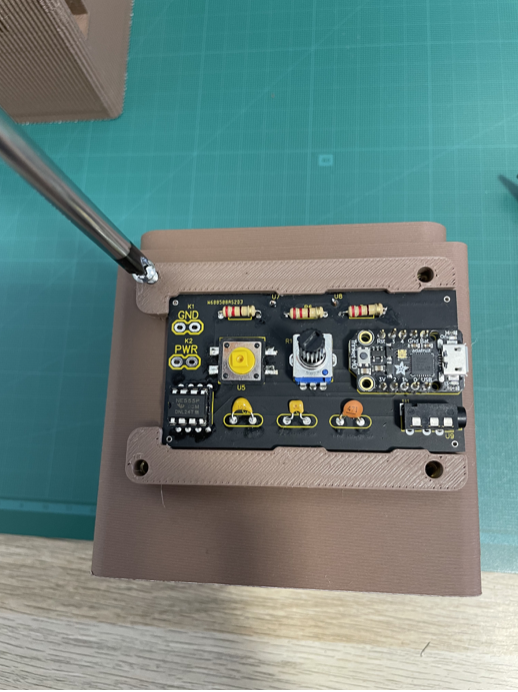
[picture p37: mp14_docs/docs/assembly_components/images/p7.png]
p7

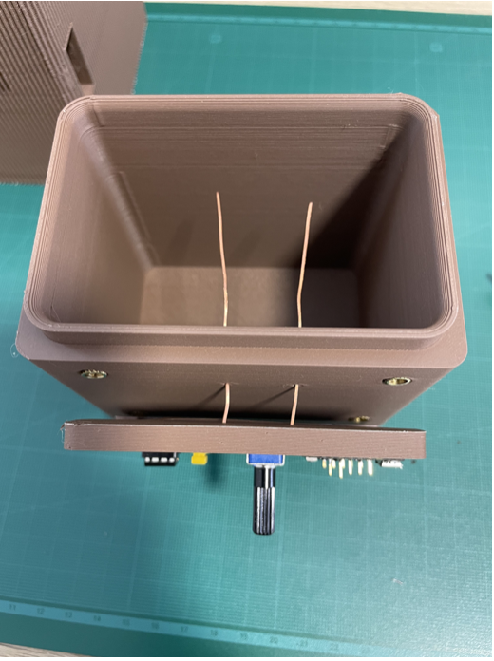
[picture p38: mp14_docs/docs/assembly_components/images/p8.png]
p8


Place the planter inside of the shell. The back of the planter should slide against the inside back of the shell so the potentiometer can fit. Once the bottom of the planter makes contact with the shell, slide the planter forward to fit into the groove while the potentiometer sticks out of the front hole.

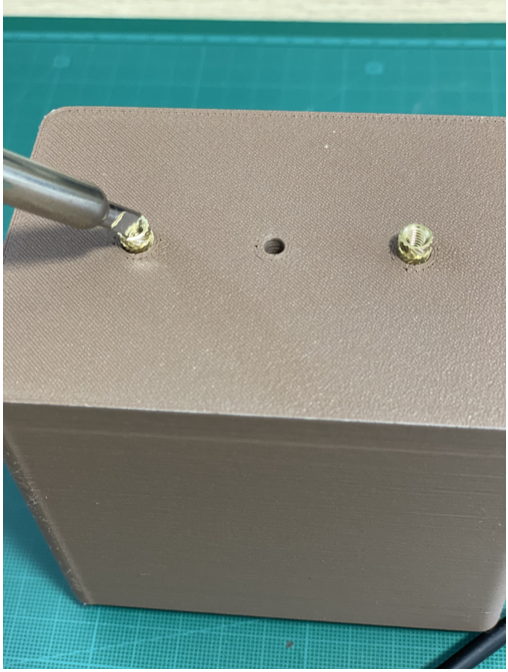
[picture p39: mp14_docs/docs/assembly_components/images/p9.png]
p9


Using pliers or scissors, remove access PLA that is blocking the two holes at the bottom of the shell.

Place the planter and shell upside down and screw two M4 screws into the two holes with a screw driver.

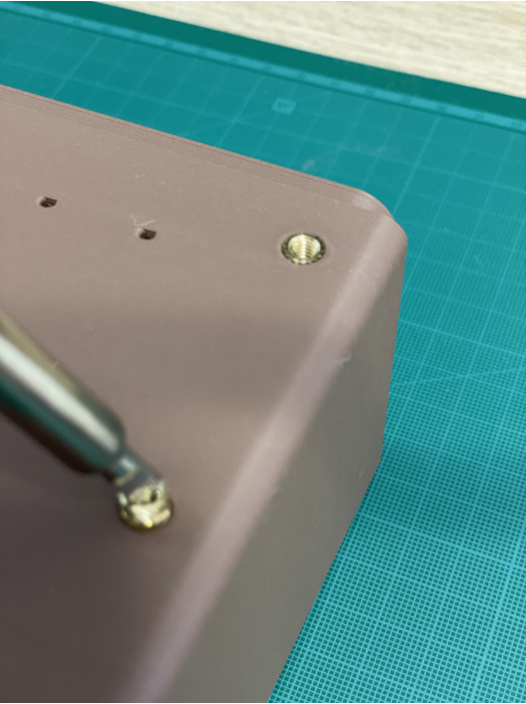
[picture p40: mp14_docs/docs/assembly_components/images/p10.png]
p10


Slide the knob onto the area of potentiometer sticking out of the shell.
Snap the button onto the tactile switch from the front of the shell. Make sure the square on the button is aligned with the square on the tactile switch.

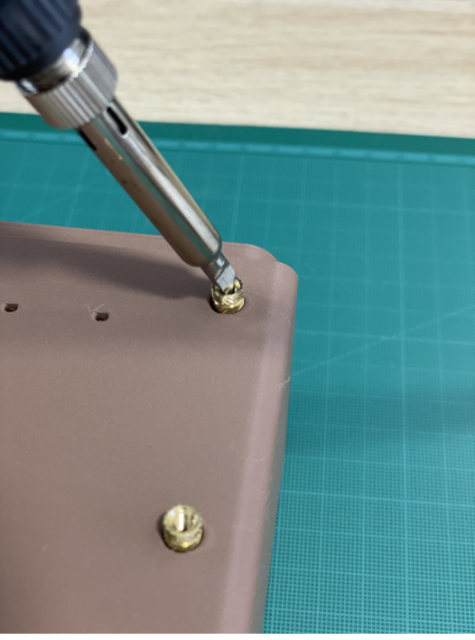
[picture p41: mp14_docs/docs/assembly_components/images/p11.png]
p11


Place the pool onto the bottom of the shell.

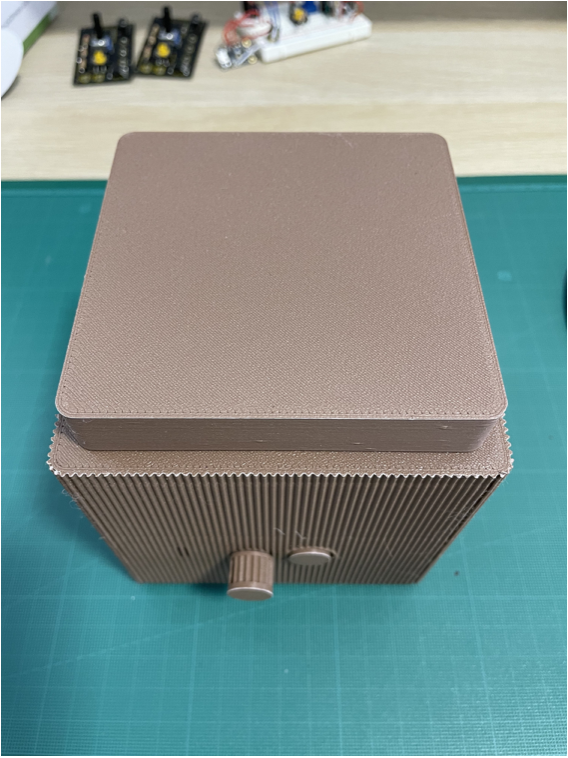
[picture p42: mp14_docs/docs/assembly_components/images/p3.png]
p3


Flip the planter over and place the hood onto the top.

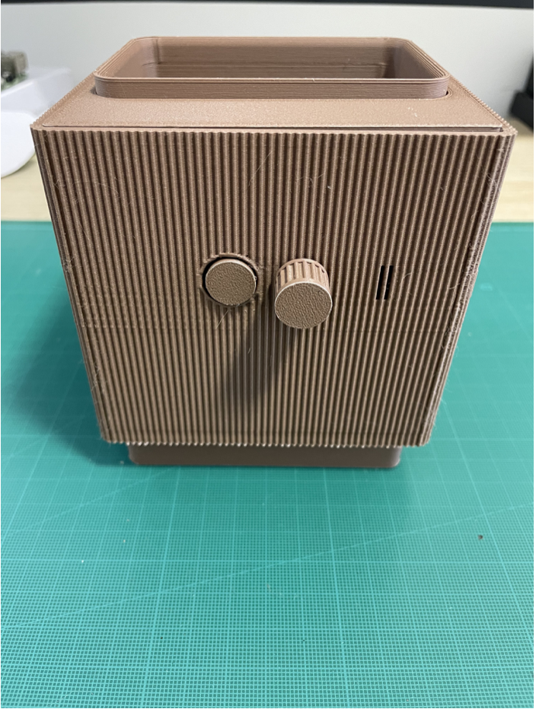
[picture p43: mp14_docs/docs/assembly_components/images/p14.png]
p14


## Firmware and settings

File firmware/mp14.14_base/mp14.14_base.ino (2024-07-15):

//Uncomment for debug mode. Use the serial monitor to see the debug values printed
#define DEBUG_MODE (1)

// Import libraries
#include "MIDIUSB.h"
#include <Arduino.h>
#include "MIDI.h"
#include <Adafruit_DotStar.h>

// Setup midi instance
MIDI_CREATE_INSTANCE(HardwareSerial, Serial1, MIDI);

// Setup main led on trinket M0
#define NUMPIXELS 1  // Number of LEDs in strip
#define DATAPIN 7
#define CLOCKPIN 8
Adafruit_DotStar strip = Adafruit_DotStar(
  NUMPIXELS, DATAPIN, CLOCKPIN, DOTSTAR_BGR);

// Setup color mapping for different musical scales
#define COLOR_MAJOR strip.gamma32(strip.ColorHSV(0, 190, 190))         // Red
#define COLOR_MINOR strip.gamma32(strip.ColorHSV(43690, 190, 190))     // Blue
#define COLOR_DIAMINOR strip.gamma32(strip.ColorHSV(60000, 190, 190))  // Magenta
#define COLOR_INDIAN strip.gamma32(strip.ColorHSV(5500, 180, 180))     // Orange
#define COLOR_CHROMATIC 0                                              // Special case for Rainbow

// Setup color mapping for diffent modes
#define COLOR_WHITE strip.gamma32(strip.ColorHSV(0, 0, 100))
#define COLOR_GREEN strip.gamma32(strip.ColorHSV(20000, 190, 100))
#define COLOR_YELLOW strip.gamma32(strip.ColorHSV(11000, 190, 190))

// Setup blicking mode for LED
unsigned long lastUpdate = 0;            // Time of the last LED update
const unsigned long pulseInterval = 30;  // Time between brightness changes during the pulse
float brightness = 0.0;                  // Current brightness level
bool increasing = true;                  // Whether the brightness is increasing or decreasing
const float maxBrightness = 0.05;        // Maximum brightness level
const float easeOutSpeed = 0.5;          // Speed of the ease-out effect
bool isNoteOn = false;

// Setup midi pause feature
unsigned long buttonPressStartTime = 0;
bool longPressTriggered = false;
bool shortPressTriggered = false;
bool isPaused = false;
const unsigned long longPressDuration = 2000;  // 2000 milliseconds = 3 seconds

// Setup pinouts of trinket M0
const byte interruptPin = A0;  //galvanometer input
const byte knobPin = A1;       //potentiometer (knob) input
const byte buttonPin = A2;
const byte ledPin = 13;

// Setup LED state
enum LedState { LED_HOME,
                LED_SCALE,
                };
LedState currentLedState = LED_HOME;

// Setup Knob state
enum KnobMode { KNOB_HOME,
                KNOB_SCALE,
                };
KnobMode currKnobMode = KNOB_HOME;
bool modeChanged = false;

const byte samplesize = 10;              //set sample array size
const byte analysize = samplesize - 1;  //trim for analysis array

byte timeout = 0;
int value = 0;
int prevValue = 0;

volatile unsigned long sample_time;  //sampling timer
volatile byte sample_idx = 0;
volatile unsigned long samples[samplesize];

unsigned long previousMillis = 0;
unsigned long currentMillis = 1;

float threshold = 1.0;   //2.3;  //change threshold multiplier
float threshMin = 1.0;  //scaling threshold min
float threshMax = 1.0;  //scaling threshold max
float knobMin = 1;
float knobMax = 1024;

//MIDI note config
const byte polyphony = 5;  //above 8 notes may run out of ram
int channel = 1;           //setting channel to 11 or 12 often helps simply computer midi routing setups
int noteMin = 48;          //C3  - keyboard note minimum
int noteMax = 96;          //C7  - keyboard note maximum

//set scaled values, sorted array, first element scale length
const int scaleCount = 5;
const int scaleLen = 13;  //maximum scale length plus 1 for 'used length'
int currScale = 0;        //current scale, default Chrom
int note_scales[scaleCount][scaleLen] = {
  { 12, 1, 2, 3, 4, 5, 6, 7, 8, 9, 10, 11, 12 },  //Chromatic
  { 7, 1, 3, 5, 6, 8, 10, 12 },                   //Major
  { 7, 1, 3, 4, 6, 8, 9, 11 },                    //DiaMinor
  { 7, 1, 2, 2, 5, 6, 9, 11 },                    //Indian
  { 7, 1, 3, 4, 6, 8, 9, 11 }                     //Minor
};
int root = 0;  //initialize for root, pitch shifting

int noteIndex = 0;
typedef struct _MIDImessage {  //build structure for Note and Control MIDImessages
  unsigned int type;
  int value;
  int velocity;
  long duration;
  long period;
  int channel;
} MIDImessage;
MIDImessage noteArray[polyphony];
MIDImessage controlMessage;  //manage MIDImessage data for Control Message (CV out)
byte controlNumber = 80;     //set to mappable control, low values may interfere with other soft synth controls.

//Helper function to map one range onto another
float mapfloat(float x, float in_min, float in_max, float out_min, float out_max) {
  return (x - in_min) * (out_max - out_min) / (in_max - in_min) + out_min;
}

void setup() {
  strip.begin();  // Initialize pins for output
  strip.show();   // Turn all LEDs off ASAP

  MIDI.begin(MIDI_CHANNEL_OMNI);
  Serial1.begin(31250);

#ifdef DEBUG_MODE
  Serial.begin(31250);
#endif
  controlMessage.value = 0;  //begin CV at 0

  pinMode(knobPin, INPUT);
  pinMode(buttonPin, INPUT_PULLUP);
  pinMode(ledPin, OUTPUT);

  attachInterrupt(digitalPinToInterrupt(buttonPin), button_isr, CHANGE);
  attachInterrupt(digitalPinToInterrupt(interruptPin), sensor_isr, RISING);
}

volatile bool buttonPressed = false;
volatile bool buttonReleased = false;

void button_isr() {
  if (digitalRead(buttonPin) == LOW) {  // Button is pressed
    if (buttonPressStartTime == 0) {
      buttonPressStartTime = millis();
      longPressTriggered = false;
    }
  } else {  // Button is released
    if (millis() - buttonPressStartTime < longPressDuration) {
      shortPressTriggered = true;
    }
    buttonPressStartTime = 0;
  }
}

void changeMode() {
  switch (currKnobMode) {
    case KNOB_SCALE:
      currKnobMode = KNOB_HOME;
      currentLedState = LED_HOME;
      break;
    case KNOB_HOME:
      currKnobMode = KNOB_SCALE;
      currentLedState = LED_SCALE;
      break;
  }
  modeChanged = true;
#ifdef DEBUG_MODE
  Serial.print("Mode: ");
  Serial.println(currKnobMode);
#endif
}

void loop() {
  // Set time to milliseconds
  currentMillis = millis();

  // Check if the button is currently pressed and held for 3 seconds
  if (buttonPressStartTime > 0 && (currentMillis - buttonPressStartTime >= longPressDuration) && !longPressTriggered) {
    longPressTriggered = true;  // Prevent multiple triggers

    // long press action
    strip.setPixelColor(0, strip.Color(255, 0, 0));  // Set LED to red
    strip.show();
    delay(500);                                    // Red LED indication for 500 ms
    strip.setPixelColor(0, strip.Color(0, 0, 0));  // Turn off LED
    strip.show();

    isPaused = !isPaused;
    //Serial.println("long press");
  }
  // Short press action
  if (shortPressTriggered) {
    shortPressTriggered = false;
    changeMode();
    Serial.println("short press");
  }

  if (!isPaused) {

    if (sample_idx >= samplesize) {
      analyzeSample();
    }

    // Switch colors based on mode
    switch (currentLedState) {
      case LED_HOME:
        blinkLed(COLOR_WHITE);
        break;
      case LED_SCALE:
        displayScaleColor();
        break;
    }

    // Pulse MIDI notes on HOME
    if (currentLedState == LED_HOME) {
      if (isNoteOn) {
        blinkLed(currentLedState == LED_HOME ? COLOR_WHITE : COLOR_GREEN);
      } else {
        // Keep the LED off or at a steady state when no note is playing
        strip.setPixelColor(0, currentLedState == LED_HOME ? COLOR_WHITE : COLOR_GREEN);
        strip.show();
      }
    } else if (currentLedState == LED_SCALE) {
      displayScaleColor();  // As implemented previously
    }

    if (modeChanged) {
      modeChanged = false;
    }

    checkKnob();
    checkNotes();
    checkControl();
  }
}

//interrupt timing sample array
void sensor_isr() {
  if (sample_idx < samplesize) {
    samples[sample_idx] = micros() - sample_time;
    sample_time = samples[sample_idx] + sample_time;  //rebuild micros() value w/o recalling
    sample_idx += 1;
  }
}

void displayScaleColor() {
  switch (currScale) {
    case 0:  // Chromatic
      animateRainbow(300);
      break;
    case 1:  // Major
      strip.setPixelColor(0, COLOR_MAJOR);
      strip.show();
      break;
    case 2:  // Minor
      strip.setPixelColor(0, COLOR_MINOR);
      strip.show();
      break;
    case 3:  // Diaminor
      strip.setPixelColor(0, COLOR_DIAMINOR);
      strip.show();
      break;
    case 4:  // Indian
      strip.setPixelColor(0, COLOR_INDIAN);
      strip.show();
      break;
  }
}

void analyzeSample() {
  unsigned long averg = 0;
  unsigned long maxim = 0;
  unsigned long minim = 100000;
  float stdevi = 0;
  unsigned long delta = 0;
  byte change = 0;

  if (sample_idx == samplesize) {  //array is full
    unsigned long sampanalysis[analysize];
    for (byte i = 0; i < analysize; i++) {
      //skip first element in the array
      sampanalysis[i] = samples[i + 1];  //load analysis table (due to volatile)

      if (sampanalysis[i] > maxim) { maxim = sampanalysis[i]; }
      if (sampanalysis[i] < minim) { minim = sampanalysis[i]; }
      averg += sampanalysis[i];
      stdevi += sampanalysis[i] * sampanalysis[i];  //prep stdevi
    }

    averg = averg / analysize;
    stdevi = sqrt(stdevi / analysize - averg * averg);  //calculate stdevu
    if (stdevi < 1) { stdevi = 1.0; }                   //min stdevi of 1
    delta = maxim - minim;

#ifdef DEBUG_MODE
    Serial.println(delta);
#endif

    //**********perform change detection
    if (delta > (stdevi * threshold)) {
      change = 1;
    }
    //*********

    if (change) {                                             // set note and control vector
      int dur = 150 + (map(delta % 127, 1, 127, 100, 2500));  //length of note
      int ramp = 3 + (dur % 100);                             //control slide rate, min 25 (or 3 ;)

      //set scaling, root key, note
      int note = map(averg % 127, 1, 127, noteMin, noteMax);  //derive note, min and max note
      note = scaleNote(note, root);                           //scale the note

      setNote(note, 100, dur, channel);

      //derive control parameters and set
      setControl(controlNumber, controlMessage.value, delta % 127, ramp);  //set the ramp rate for the control
    }

    //reset array for next sample
    sample_idx = 0;
  }
}

void blinkLed(uint32_t color) {
  unsigned long currentMillis = millis();

  if (isNoteOn) {
    if (currentMillis - lastUpdate > pulseInterval) {
      lastUpdate = currentMillis;

      if (increasing) {
        brightness += 0.1;
        if (brightness >= maxBrightness) {
          increasing = false;
        }
      } else {
        brightness -= 0.1;
        if (brightness <= 0) {
          increasing = true;
        }
      }
    }
  } else {
    if (brightness > 0) {
      brightness -= easeOutSpeed;
    }
  }

  // Apply the calculated brightness to the color
  int red = (int)(((color >> 16) & 0xFF) * brightness);
  int green = (int)(((color >> 8) & 0xFF) * brightness);
  int blue = (int)((color & 0xFF) * brightness);

  strip.setPixelColor(0, strip.Color(red, green, blue));
  strip.show();
}


int scaleSearch(int note) {
  int scalesize = (note_scales[currScale][0]);
  for (byte i = 1; i < scalesize; i++) {
    if (note == note_scales[currScale][i]) {
      return note;
    } else {
      if (note < note_scales[currScale][i]) { return note_scales[currScale][i]; }
    }  //highest scale value less than or equal to note
    //otherwise continue search
  }
  //didn't find note and didn't pass note value, uh oh!
  return 6;  //give arbitrary value rather than fail
}

int scaleNote(int note, int root) {
  //input note mod 12 for scaling, note/12 octave
  //search array for nearest note, return scaled*octave
  int scaled = note % 12;
  int octave = note / 12;
  //search entire array and return closest scaled note
  scaled = scaleSearch(scaled);
  scaled = (scaled + (12 * octave)) + root;  //apply octave and root
  return scaled;
}

// First parameter is the event type (0x09 = note on, 0x08 = note off).
// Second parameter is note-on/note-off, combined with the channel.
// Channel can be anything between 0-15. Typically reported to the user as 1-16.
// Third parameter is the note number (48 = middle C).
// Fourth parameter is the velocity (64 = normal, 127 = fastest).

void MIDINoteOn(byte channel, byte pitch, byte velocity) {
  midiEventPacket_t noteOn = { 0x09, 0x90 | channel, pitch, velocity };
  MidiUSB.sendMIDI(noteOn);
  MIDI.sendNoteOn(pitch, velocity, channel);
  isNoteOn = true;
}

void MIDINoteOff(byte channel, byte pitch, byte velocity) {
  midiEventPacket_t noteOff = { 0x08, 0x80 | channel, pitch, velocity };
  MidiUSB.sendMIDI(noteOff);
  MIDI.sendNoteOff(pitch, velocity, channel);
  isNoteOn = false;
}

// First parameter is the event type (0x0B = control change).
// Second parameter is the event type, combined with the channel.
// Third parameter is the control number number (0-119).
// Fourth parameter is the control value (0-127).

void MIDIControlChange(byte channel, byte control, byte value) {
  midiEventPacket_t event = { 0x0B, 0xB0 | channel, control, value };
  MidiUSB.sendMIDI(event);
}

void setNote(int value, int velocity, long duration, int notechannel) {
  //find available note in array (velocity = 0);
  for (int i = 0; i < polyphony; i++) {
    if (!noteArray[i].velocity) {
      //if velocity is 0, replace note in array
      noteArray[i].type = 0;
      noteArray[i].value = value;
      noteArray[i].velocity = velocity;
      noteArray[i].duration = currentMillis + duration;
      noteArray[i].channel = notechannel;

      MIDINoteOn(channel, value, velocity);
      break;
    }
  }
}

void checkKnob() {
  int val = analogRead(knobPin);
  if (currKnobMode == KNOB_SCALE) {
    currScale = map(val, knobMin, knobMax, 0, scaleCount);
    setScaleColor(currScale);
  }
}

void setScaleColor(int scale) {
  uint32_t color;
  switch (scale) {
    case 0:
      color = COLOR_CHROMATIC;
      break;
    case 1:
      color = COLOR_MAJOR;
      break;
    case 2:
      color = COLOR_MINOR;
      break;
    case 3:
      color = COLOR_DIAMINOR;
      break;
    case 4:
      color = COLOR_INDIAN;
      break;
  }

  if (color == COLOR_CHROMATIC) {
    // Logic for rainbow color
    animateRainbow(300);
  } else {
    strip.setPixelColor(0, color);
    strip.show();
  }
}

void animateRainbow(unsigned long interval) {
  static unsigned long lastChangeTime = 0;
  static int colorIndex = 0;
  unsigned long currentMillis = millis();

  if (currentMillis - lastChangeTime >= interval) {
    lastChangeTime = currentMillis;
    uint32_t colors[] = { COLOR_MAJOR, COLOR_MINOR, COLOR_DIAMINOR, COLOR_INDIAN };
    strip.setPixelColor(0, colors[colorIndex]);
    colorIndex = (colorIndex + 1) % (sizeof(colors) / sizeof(colors[0]));
    strip.show();
  }
}

void checkNotes() {
  //send noteOff for all notes with non-zero velocity and expired duration
  for (int i = 0; i < polyphony; i++) {
    if ((noteArray[i].velocity) && (noteArray[i].duration <= currentMillis)) {
      MIDINoteOff(channel, noteArray[i].value, 0);
      noteArray[i].velocity = 0;
    }
  }
}

void setControl(int type, int value, int velocity, long duration) {
  controlMessage.type = type;
  controlMessage.value = value;
  controlMessage.velocity = velocity;
  controlMessage.period = duration;
  controlMessage.duration = currentMillis + duration;  //schedule for update cycle
}

void checkControl() {
  //need to make this a smooth slide transition, using high precision
  //distance is current minus goal
  signed int distance = controlMessage.velocity - controlMessage.value;
  //if still sliding
  if ((distance != 0) && (currentMillis > controlMessage.duration)) {
    controlMessage.duration = currentMillis + controlMessage.period;  //extend duration
    if (distance > 0) {
      controlMessage.value += 1;
    } else {
      controlMessage.value -= 1;
    }

    //send MIDI control message after ramp duration expires, on each increment
    MIDIControlChange(channel, controlMessage.type, controlMessage.value);
  }
}

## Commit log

2024-06-24 complete assembly manual
2024-07-15 stl file added
    [BRACKET.stl, BUTTON.stl, HOOD.stl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]
